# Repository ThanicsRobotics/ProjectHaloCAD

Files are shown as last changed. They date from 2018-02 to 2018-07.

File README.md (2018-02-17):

# ProjectHaloCAD
This is the official repository of the Thanics Halo open-source project. This is a project powered by the Raspberry Pi Compute Module 3, both the drone and controller use this module, along with several coprocessors. This project is not complete yet and all documaentation has not been uploaded, but feel free to follow along with our progress or use any of our 3D parts or software, as long as you attribute us.
## Background
### The Drone
The Thanics Halo drone utilizes stereo camera vision and ultrasonic sensors to accomplish spherical obstacle avoidance. The Halo drone is built to be versatile with a variety of cameras of different imaging types. The project focuses primarily on 360 (spherical) imaging and spherical video live streaming.
halo_assy_2017-jul-01_08-42-29pm-000_customizedview22054851270
### The Controller
The controller for the Halo drone is equally as innovative as the drone. This is a hybrid controller, able to be used either with two thumbs (traditional), or wrist-mounted for voice or touchscreen control.
halo controller v137 2
## Files
### MCAD Files: 
All mechanical part files for the project (source files are in Fusion 360 archive file .f3d or .f3z)
### ECAD Files: 
All electronics schematics, libraries and Autodesk EAGLE source .sch and .brd files
### Block Diagrams
Higher-level system block diagrams for the Drone and Controller
### Software:
For this project's source code, see our other repository: https://github.com/ThanicsRobotics/ProjectHalo

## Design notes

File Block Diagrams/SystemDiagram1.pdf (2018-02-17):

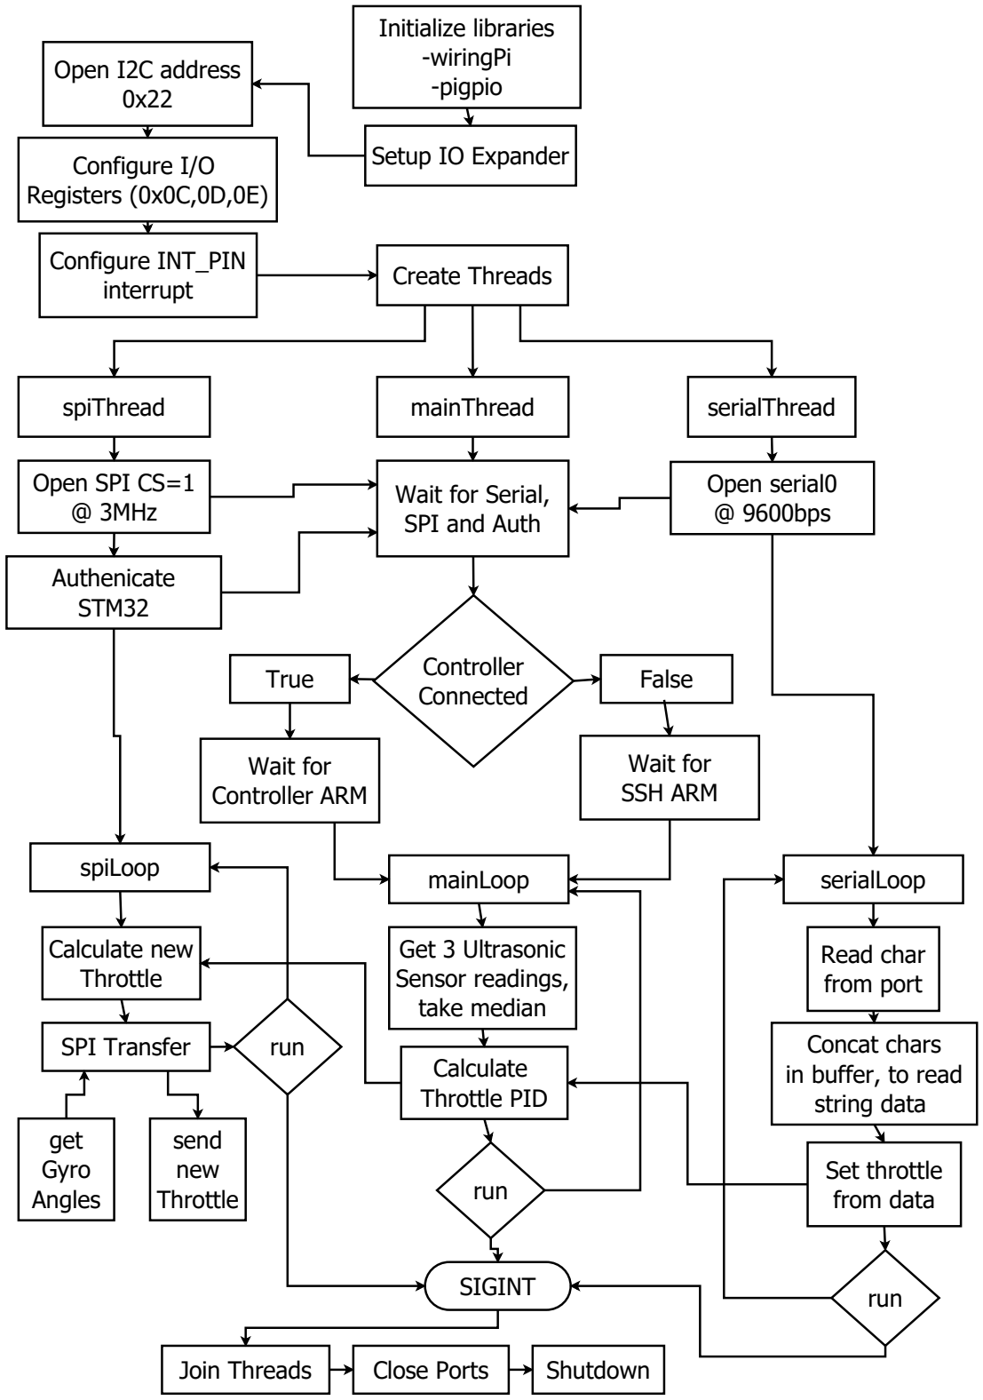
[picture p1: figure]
Initialize libraries -wiringPi -pigpio; Controller; Connected True; False; Wait for Controller ARM; Setup IO Expander; Open I2C address 0x22; Configure I/O Registers (0x0C,0D,0E); Configure INT_PIN; interrupt; Create Threads; spiThread; mainThread; serialThread; Open SPI CS=1 @ 3MHz; Authenicate STM32; Wait for Serial, SPI and Auth; Open serial0 @ 9600bps; Wait for SSH ARM; mainLoop; Get 3 Ultrasonic Sensor readings, take median; Calculate Throttle PID; spiLoop; serialLoop; run; Calculate new Throttle; SPI Transfer; get Gyro Angles; send new Throttle; Read char from port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

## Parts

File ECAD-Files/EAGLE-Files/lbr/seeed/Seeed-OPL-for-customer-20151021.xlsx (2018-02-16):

OPL list
Seeed SKU | MPN | Description | Category | Package | Manufacturer | Datasheet | Price（$）/pcs | Pieces/set | Solder points Qty | Assem.Cost/pcs（$） | Image URL | Distributor-URL
306010055 | FC-135 | SMD Crystal ABS07-32.768KHZ-7pF-20ppm-70K; | Crystal Oscillator | 2P-L3.2*W1.5mm | Xinhunjing | http://www.seeedstudio.com/wiki/images/7/78/306010055.pdf | 0.350 | 5 | 4 | 0.40 |  | http://www.seeedstudio.com/depot/OPLopen-parts-library-catalog-c-136_138/#306010055
306010005 | 49S | DIP Crystal 25MHz-20pF-20ppm;HC49US | Crystal Oscillator | HC49US | Xinhunjing | http://www.seeedstudio.com/wiki/images/5/5e/306010005.pdf | 0.150 | 10 | 2 | 0.20 |  | http://www.seeedstudio.com/depot/OPLopen-parts-library-catalog-c-136_138/#306010005
306010037 | 49S/18PF | DIP Crystal 16MHz-18pF-30ppm-50R; | Crystal Oscillator | HC49/US | Xinhunjing | http://www.seeedstudio.com/wiki/images/5/57/306010037.pdf | 0.150 | 10 | 2 | 0.20 |  | http://www.seeedstudio.com/depot/OPLopen-parts-library-catalog-c-136_138/#306010037
306010054 | X053201602002 | SMD 16MHz-8pF-20ppm-40R | Crystal Oscillator | 2P-SMD-5.0X3.2 | JINGPENGYUAN | http://www.seeedstudio.com/wiki/images/9/9f/0500290P1.pdf | 0.350 | 5 | 2 | 0.20 |  | http://www.seeedstudio.com/depot/OPLopen-parts-library-catalog-c-136_138/#0500290P1
306010047 | 5032/2P | SMD Crystal 12Mhz-20pF-20ppm-40R; | Crystal Oscillator | 2P-L5.0*W3.2mm | Xinhunjing | http://www.seeedstudio.com/wiki/images/c/c7/306010047.pdf | 0.450 | 5 | 2 | 0.20 |  | http://www.seeedstudio.com/depot/OPLopen-parts-library-catalog-c-136_138/#306010047
306010004 | 5032/4P | SMD Crystal 8MHz-20pF-20ppm; | Crystal Oscillator | 2P-L5.0*W3.2mm | Xinhunjing | http://www.seeedstudio.com/wiki/images/9/91/306010004.pdf | 0.450 | 5 | 2 | 0.20 |  | http://www.seeedstudio.com/depot/OPLopen-parts-library-catalog-c-136_138/#306010004
306010033 | 49S8M | DIP Crystal 8MHz-20pF-20ppm-60R; | Crystal Oscillator | HC49S | Xinhunjing | http://www.seeedstudio.com/wiki/images/c/ca/306010033.pdf | 0.150 | 10 | 2 | 0.20 |  | http://www.seeedstudio.com/depot/OPLopen-parts-library-catalog-c-136_138/#306010033
305030028 | 2N7002,215 | SMD MOSFET N-CH 60V-300mA Logic Level FET; | Transistor | SOT-23 | NXP | http://www.seeedstudio.com/wiki/images/c/c6/305030028.pdf | 0.050 | 30 | 3 | 0.30 |  | http://www.seeedstudio.com/depot/OPLopen-parts-library-catalog-c-136_138/#305030028
305030015 | CJ2302 | SMD MOSFET N-CH 20V 2.1A | Transistor | SOT23 | JCET | http://www.seeedstudio.com/wiki/images/e/e7/0440200P1.pdf | 0.100 | 10 | 3 | 0.30 |  | http://www.seeedstudio.com/depot/OPLopen-parts-library-catalog-c-136_138/#0440200P1
305030018 | Si2343CDS | SMD MOSFET P-CH 30V-5.9A | Transistor | SOT-23 | Vishay Siliconix |  | 0.700 | 5 | 3 | 0.30 |  | http://www.seeedstudio.com/depot/OPLopen-parts-library-catalog-c-136_138/#305030018
305030014 | CJ2305 | SMD MOSFET P-CH -8V -4.1A | Transistor | SOT-23 | JCET | http://www.seeedstudio.com/wiki/images/a/ac/0440210P1.pdf | 0.100 | 10 | 3 | 0.30 |  | http://www.seeedstudio.com/depot/OPLopen-parts-library-catalog-c-136_138/#0440210P1
305010018 | S9013 | SMD Transistors NPN 25V-500mA | Transistor | SOT-23 | JCET | http://www.seeedstudio.com/wiki/images/6/67/0400000P1.pdf | 0.040 | 50 | 3 | 0.30 |  | http://www.seeedstudio.com/depot/OPLopen-parts-library-catalog-c-136_138/#0400000P1
305020006 | S8550 | SMD Transistors PNP 25V-500mA | Transistor | SOT-23 |  | http://www.seeedstudio.com/wiki/images/e/e5/0410030P1.pdf | 0.040 | 50 | 3 | 0.30 |  | http://www.seeedstudio.com/depot/OPLopen-parts-library-catalog-c-136_138/#0410030P1
305010017 | S8050 | SMD Transistors NPN 25V-500mW; | Transistor | SOT-23 | JCET | http://www.seeedstudio.com/wiki/images/b/ba/305010017.pdf | 0.040 | 50 | 3 | 0.30 |  | http://www.seeedstudio.com/depot/OPLopen-parts-library-catalog-c-136_138/#305010017
305010022 | S9014J6 | SMD Transistor NPN 50V-100mA; | Transistor | SOT-23 | Changjiang | http://www.seeedstudio.com/wiki/images/2/2c/305010022.pdf | 0.050 | 30 | 3 | 0.30 |  | http://www.seeedstudio.com/depot/OPLopen-parts-library-catalog-c-136_138/#305010022
312010004 | KS-12065D03YA | DIP Buzzer 3V,30mA, 2700±300Hz | Audio product | 2P-7.6-D12*H6.5mm | Guangjixing | http://www.seeedstudio.com/wiki/images/c/cb/312020003.pdf | 0.500 | 5 | 2 | 0.20 |  | http://www.seeedstudio.com/depot/OPLopen-parts-library-catalog-c-136_138/#312010004
302020027 | TAJD477M006RNJ | SMD CAP Tantalum 470uF-6.3V;D | Capacitor | AVX-D | AVX |  | 0.500 | 5 | 2 | 0.20 |  | http://www.seeedstudio.com/depot/OPLopen-parts-library-catalog-c-136_138/#302020027
302030031 |  | DIP CAP Aluminum 100uF-16V | Capacitor | Radial-D5.0*H7.0mm | JWCO | http://www.seeedstudio.com/wiki/images/1/14/302030031.pdf | 0.030 | 50 | 2 | 0.20 |  | http://www.seeedstudio.com/depot/OPLopen-parts-library-catalog-c-136_138/#302030031
302020025 | TAJC107K010RNJ | SMD CAP Tantalum 100uF-10V 10% | Capacitor | AVX-C | AVX | http://www.seeedstudio.com/wiki/images/a/ae/0130170P1.pdf | 0.200 | 10 | 2 | 0.20 |  | http://www.seeedstudio.com/depot/OPLopen-parts-library-catalog-c-136_138/#0130170P1
302020022 | TAJC476K016RNJ | SMD CAP Tantalum 47uF-16V | Capacitor | AVX-C | AVX | http://www.seeedstudio.com/wiki/images/c/c7/302020022.pdf | 0.200 | 10 | 2 | 0.20 |  | http://www.seeedstudio.com/depot/OPLopen-parts-library-catalog-c-136_138/#302020022
302020020 | TAJB476K010RNJ | SMD CAP Tantalum 47uF-10V 10% | Capacitor | AVX-B | AVX | http://www.seeedstudio.com/wiki/images/f/fb/0130180P1.pdf | 0.200 | 10 | 2 | 0.20 |  | http://www.seeedstudio.com/depot/OPLopen-parts-library-catalog-c-136_138/#0130180P1
302020005 | TAJC476K006RNJ | SMD CAP Tantalum 47uF-6.3V | Capacitor | AVX-A | AVX |  | 0.150 | 20 | 2 | 0.20 |  | http://www.seeedstudio.com/depot/OPLopen-parts-library-catalog-c-136_138/#302020005
302020026 | TAJC226K025RNJ | SMD CAP Tantalum 22uF-25V 10% 2312 | Capacitor | AVX-C | AVX | http://www.seeedstudio.com/wiki/images/f/fd/0130360P1.pdf | 0.370 | 10 | 2 | 0.20 |  | http://www.seeedstudio.com/depot/OPLopen-parts-library-catalog-c-136_138/#0130360P1
302020021 | TAJB226K010RNJ | SMD CAP Tantalum 22uF-10V 10% | Capacitor | AVX-B | AVX | http://www.seeedstudio.com/wiki/images/8/82/0130240P1.pdf | 0.130 | 20 | 2 | 0.20 |  | http://www.seeedstudio.com/depot/OPLopen-parts-library-catalog-c-136_138/#0130240P1
302010171 | CC0805MKX5R5BB226 | SMD CAP Ceramic 22uF-6.3V-20%-X5R; | Capacitor | 0805 | YAGEO |  | 0.050 | 50 | 2 | 0.20 |  | http://www.seeedstudio.com/depot/OPLopen-parts-library-catalog-c-136_138/#302010171
302010181 | CC1206KKX5R8BB106 | SMD CAP Ceramic 10uF-25V-10%-X5R | Capacitor | 1206 | YAGEO |  | 0.130 | 20 | 2 | 0.20 |  | http://www.seeedstudio.com/depot/OPLopen-parts-library-catalog-c-136_138/#302010181
302010178 | CC0805KKX5R8BB106 | SMD CAP Ceramic 10uF-25V-10%-X5R | Capacitor | 0805 | YAGEO | http://www.seeedstudio.com/wiki/images/2/20/0100080P1.pdf | 0.050 | 50 | 2 | 0.20 |  | http://www.seeedstudio.com/depot/OPLopen-parts-library-catalog-c-136_138/#0100080P1
302020019 | TAJB106K016RNJ | SMD CAP Tantalum 10uF-16V 10% | Capacitor | AVX-B | AVX | http://www.seeedstudio.com/wiki/images/f/f6/0130120P1.pdf | 0.150 | 20 | 2 | 0.20 |  | http://www.seeedstudio.com/depot/OPLopen-parts-library-catalog-c-136_138/#0130120P1
302020002 | TAJA106K016RNJ | SMD CAP Tantalum 10uF-16V 10% | Capacitor | AVX-A | AVX | http://www.seeedstudio.com/wiki/images/1/1b/0130050P1.pdf | 0.130 | 20 | 2 | 0.20 |  | http://www.seeedstudio.com/depot/OPLopen-parts-library-catalog-c-136_138/#0130050P1
302020011 | TAJA106K010RNJ | SMD CAP Tantalum 10uF-10V 10% | Capacitor | AVX-A | AVX | http://www.seeedstudio.com/wiki/images/5/59/0130040P1.pdf (http://www.seeedstudio.com/wiki/images/0/0d/302010146.pdf) | 0.130 | 20 | 2 | 0.20 |  | http://www.seeedstudio.com/depot/OPLopen-parts-library-catalog-c-136_138/#0130040P1
302010243 | CC1206KKX5R9BB475 | SMD CAP Ceramic 4.7uF-50V-10%-X5R; | Capacitor | 1206 | YAGEO |  | 0.250 | 10 | 2 | 0.20 |  | http://www.seeedstudio.com/depot/OPLopen-parts-library-catalog-c-136_138/#302010243
302010146 | CC0805KKX5R8BB475 | SMD CAP Ceramic 4.7uF-25V-10%-X5R;0805 | Capacitor | C0805 | YAGEO | http://www.seeedstudio.com/wiki/images/0/0d/302010146.pdf | 0.040 | 50 | 2 | 0.20 |  | http://www.seeedstudio.com/depot/OPLopen-parts-library-catalog-c-136_138/#302010146
302010111 | CC0603KRX5R6BB475 | SMD CAP Ceramic 4.7uF-10V-10%-X5R; | Capacitor | 0603 | YAGEO |  | 0.040 | 50 | 2 | 0.20 |  | http://www.seeedstudio.com/depot/OPLopen-parts-library-catalog-c-136_138/#302010111
302010019 | CC0402MRX5R5BB475 | SMD CAP Ceramic 4.7uF-6.3V-20%-X5R | Capacitor | 0402 | YAGEO |  | 0.200 | 10 | 2 | 0.20 |  | http://www.seeedstudio.com/depot/OPLopen-parts-library-catalog-c-136_138/#302010019
302010148 | CC0805KKX7R8BB225 | SMD CAP Ceramic 2.2uF-25V-10%-X7R;0805 | Capacitor | C0805 | YAGEO | http://www.seeedstudio.com/wiki/images/a/ac/302010056.pdf | 0.050 | 50 | 2 | 0.20 |  | http://www.seeedstudio.com/depot/OPLopen-parts-library-catalog-c-136_138/#302010148
302010179 | CC0805KKX7R8BB105 | SMD CAP Ceramic 1uF-25V-10%-X7R | Capacitor | 0805 | YAGEO | http://www.seeedstudio.com/wiki/images/8/89/0100440P1.pdf (http://www.seeedstudio.com/wiki/images/a/ac/302010056.pdf) | 0.030 | 50 | 2 | 0.20 |  | http://www.seeedstudio.com/depot/OPLopen-parts-library-catalog-c-136_138/#0100440P1
302010139 | CC0603KRX7R8BB105 | SMD CAP Ceramic 1uF-25V-10%-X7R | Capacitor | 0603 | YAGEO | http://www.seeedstudio.com/wiki/images/a/af/0100340P1.pdf (http://www.seeedstudio.com/wiki/File:302010056.pdf) | 0.015 | 100 | 2 | 0.20 |  | http://www.seeedstudio.com/depot/OPLopen-parts-library-catalog-c-136_138/#0100340P1
302010040 | CC0402KRX5R6BB105 | SMD CAP Ceramic 1uF-10V-10%-X5R | Capacitor | 0402 | YAGEO |  | 0.015 | 100 | 2 | 0.20 |  | http://www.seeedstudio.com/depot/OPLopen-parts-library-catalog-c-136_138/#302010040
302010073 | CC0603KRX7R8BB224 | SMD CAP Ceramic 220nF-25V-10%-X7R;0603 | Capacitor | 0603 | YAGEO | http://www.seeedstudio.com/wiki/images/a/ac/302010056.pdf | 0.015 | 100 | 2 | 0.20 |  | http://www.seeedstudio.com/depot/OPLopen-parts-library-catalog-c-136_138/#302010073
302010165 | CC0805KRX7R9BB104 | SMD CAP Ceramic 100nF-50V-10%-X7R; | Capacitor | 0805 | YAGEO | http://www.seeedstudio.com/wiki/File:302010056.pdf (http://www.seeedstudio.com/wiki/images/a/ac/302010056.pdf) | 0.015 | 100 | 2 | 0.20 |  | http://www.seeedstudio.com/depot/OPLopen-parts-library-catalog-c-136_138/#302010165
302010138 | CC0603KRX7R9BB104 | SMD CAP Ceramic 100nF-50V-10%-X7R | Capacitor | 0603 | YAGEO | http://www.seeedstudio.com/wiki/images/3/35/0100020P1.pdf | 0.015 | 100 | 2 | 0.20 |  | http://www.seeedstudio.com/depot/OPLopen-parts-library-catalog-c-136_138/#0100020P1
302010024 | CC0402KRX7R8BB104 | SMD CAP Ceramic 100nF-25V-10%-X7R | Capacitor | 0402 | YAGEO | http://www.seeedstudio.com/wiki/images/a/ac/302010056.pdf | 0.015 | 100 | 2 | 0.20 |  | http://www.seeedstudio.com/depot/OPLopen-parts-library-catalog-c-136_138/#302010024
302010002 | CC0402KRX7R8BB473 | SMD CAP Ceramic 47nF-25V-10%-X7R; | Capacitor | 0402 | YAGEO |  | 0.010 | 100 | 2 | 0.20 |  | http://www.seeedstudio.com/depot/OPLopen-parts-library-catalog-c-136_138/#302010002
302010088 | CC0603KRX7R9BB333 | SMD CAP Ceramic 33nF-50V-10%-X7R;0603 | Capacitor | 0603 | YAGEO | http://www.seeedstudio.com/wiki/images/a/ac/302010056.pdf | 0.015 | 100 | 2 | 0.20 |  | http://www.seeedstudio.com/depot/OPLopen-parts-library-catalog-c-136_138/#302010088
302010095 | CC0603KRX7R9BB223 | SMD CAP Ceramic 22nF-50V-10%-X7R;0603 | Capacitor | C0603 | YAGEO | http://www.seeedstudio.com/wiki/images/a/ac/302010056.pdf | 0.010 | 100 | 2 | 0.20 |  | http://www.seeedstudio.com/depot/OPLopen-parts-library-catalog-c-136_138/#302010095
302010202 |  | DIP CAP Ceramic Disc 10nF-50V-Y5V | Capacitor | Radial-Disc-2.5-D4.0mm |  |  | 0.015 | 100 | 2 | 0.20 |  | http://www.seeedstudio.com/depot/OPLopen-parts-library-catalog-c-136_138/#302010202
302010140 | CC0603KRX7R9BB103 | SMD CAP Ceramic 10nF-50V-10%-X7R | Capacitor | 0603 | YAGEO | http://www.seeedstudio.com/wiki/images/e/eb/0100350P1.pdf (http://www.seeedstudio.com/wiki/images/f/f0/302010067.pdf%20302010094) | 0.010 | 100 | 2 | 0.20 |  | http://www.seeedstudio.com/depot/OPLopen-parts-library-catalog-c-136_138/#0100350P1
302010006 | CC0402KRX7R9BB103 | SMD CAP Ceramic 10nF-50V-10%-X7R | Capacitor | 0402 | YAGEO | http://www.seeedstudio.com/wiki/images/f/f0/302010067.pdf | 0.010 | 100 | 2 | 0.20 |  | http://www.seeedstudio.com/depot/OPLopen-parts-library-catalog-c-136_138/#302010006
302010144 | CC0603KRX7R9BB472 | SMD CAP Ceramic 4.7nF-50V-10%-X7R | Capacitor | 0603 | YAGEO | http://www.seeedstudio.com/wiki/images/f/fd/0130360P1.pdf | 0.010 | 100 | 2 | 0.20 |  | http://www.seeedstudio.com/depot/OPLopen-parts-library-catalog-c-136_138/#0100850P1
302010056 | CC0603KRX7R9BB222 | SMD CAP Ceramic 2.2nF-50V-10%-X7R | Capacitor | 0603 | YAGEO | http://www.seeedstudio.com/wiki/images/a/ac/302010056.pdf | 0.010 | 100 | 2 | 0.20 |  | http://www.seeedstudio.com/depot/OPLopen-parts-library-catalog-c-136_138/#302010056
302010141 | CC0603KRX7R9BB102 | SMD CAP Ceramic 1nF-50V-10%-X7R | Capacitor | 0603 | YAGEO | http://www.seeedstudio.com/wiki/images/c/cf/0100370P1.pdf | 0.010 | 100 | 2 | 0.20 |  | http://www.seeedstudio.com/depot/OPLopen-parts-library-catalog-c-136_138/#0100370P1
302010005 | CC0402KRX7R9BB102 | SMD CAP Ceramic 1nF-50V-10%-X7R; | Capacitor | 0402 | YAGEO |  | 0.050 | 50 | 2 | 0.20 |  | http://www.seeedstudio.com/depot/OPLopen-parts-library-catalog-c-136_138/#302010005
302010094 | CC0603JRNPO9BN221 | SMD CAP Ceramic 220pF-50V-5%-NPO; | Capacitor | C0603 | YAGEO | http://www.seeedstudio.com/wiki/images/f/f0/302010067.pdf 302010094 (http://www.seeedstudio.com/wiki/File:302010067.pdf) | 0.020 | 100 | 2 | 0.20 |  | http://www.seeedstudio.com/depot/OPLopen-parts-library-catalog-c-136_138/#302010094
302010013 | CC0402JRNPO9BN221 | SMD CAP Ceramic 220pF-50V-5%-NPO | Capacitor | 0402 | YAGEO | http://www.seeedstudio.com/wiki/images/f/f0/302010067.pdf | 0.030 | 50 | 2 | 0.20 |  | http://www.seeedstudio.com/depot/OPLopen-parts-library-catalog-c-136_138/#302010013
302010076 | CC0603JRNPO9BN101 | SMD CAP Ceramic 100pF-50V-5%-NPO;0603 | Capacitor | 0603 | YAGEO | http://www.seeedstudio.com/wiki/images/f/f0/302010067.pdf | 0.010 | 100 | 2 | 0.20 |  | http://www.seeedstudio.com/depot/OPLopen-parts-library-catalog-c-136_138/#302010076
302010126 | CC0603JRNPO9BN390 | SMD CAP Ceramic 39pF-50V-5%-NPO;0603 | Capacitor | C0603 | YAGEO | http://www.seeedstudio.com/wiki/images/f/f0/302010067.pdf (http://www.seeedstudio.com/wiki/images/0/03/0100230P1.pdf) | 0.010 | 100 | 2 | 0.20 |  | http://www.seeedstudio.com/depot/OPLopen-parts-library-catalog-c-136_138/#302010126
302010150 | CC0805JRNPO9BN270 | SMD CAP Ceramic 27pF-50V-5%-NPO | Capacitor | 0805 | YAGEO | http://www.seeedstudio.com/wiki/images/b/be/320020004.png | 0.030 | 50 | 2 | 0.20 |  | http://www.seeedstudio.com/depot/OPLopen-parts-library-catalog-c-136_138/#302010150
302010142 | CC0603JRNPO9BN270 | SMD CAP Ceramic 27pF-50V-5%-NPO | Capacitor | 0603 | YAGEO | http://www.seeedstudio.com/wiki/images/0/01/0100410P1.pdf (http://www.seeedstudio.com/wiki/images/b/be/320020004.png) | 0.010 | 100 | 2 | 0.20 |  | http://www.seeedstudio.com/depot/OPLopen-parts-library-catalog-c-136_138/#0100410P1
302010027 | CC0402JRNPO9BN270 | SMD CAP Ceramic 27pF-50V-5%-NPO | Capacitor | 0402 | YAGEO | http://www.seeedstudio.com/wiki/images/b/be/320020004.png | 0.010 | 100 | 2 | 0.20 |  | http://www.seeedstudio.com/depot/OPLopen-parts-library-catalog-c-136_138/#302010027
302010143 | CC0603JRNPO9BN220 | SMD CAP Ceramic 22pF-50V-5%-NPO | Capacitor | 0603 | YAGEO | http://www.seeedstudio.com/wiki/images/7/73/0100620P1.pdf | 0.010 | 100 | 2 | 0.20 |  | http://www.seeedstudio.com/depot/OPLopen-parts-library-catalog-c-136_138/#0100620P1
302010018 | CC0402JRNPO9BN220 | SMD CAP Ceramic 22pF-50V-5%-NPO | Capacitor | 0402 | YAGEO | http://www.seeedstudio.com/wiki/File:302010067.pdf (http://www.seeedstudio.com/wiki/images/b/be/320020004.png) | 0.010 | 100 | 2 | 0.20 |  | http://www.seeedstudio.com/depot/OPLopen-parts-library-catalog-c-136_138/#302010018
302010162 | CC0805JRNPO9BN180 | SMD CAP Ceramic 18pF-50V-5%-NPO | Capacitor | 0805 | YAGEO |  | 0.010 | 100 | 2 | 0.20 |  | http://www.seeedstudio.com/depot/OPLopen-parts-library-catalog-c-136_138/#302010162
302010016 | CC0402JRNPO9BN180 | SMD CAP Ceramic 18pF-50V-5%-NPO | Capacitor | 0402 | YAGEO |  | 0.010 | 100 | 2 | 0.20 |  | http://www.seeedstudio.com/depot/OPLopen-parts-library-catalog-c-136_138/#302010016
302010083 | CC0603JRNPO9BN180 | SMD CAP Ceramic 18pF-50V-5%-NPO; | Capacitor | 0603 | YAGEO | http://www.seeedstudio.com/wiki/images/7/77/320020027.png | 0.010 | 100 | 2 | 0.20 |  | http://www.seeedstudio.com/depot/OPLopen-parts-library-catalog-c-136_138/#302010083
302010082 | CC0603JRNPO9BN150 | SMD CAP Ceramic 15pF-50V-5%-NPO;0603 | Capacitor | 0603 | YAGEO | http://www.seeedstudio.com/wiki/images/f/f0/302010067.pdf (http://www.seeedstudio.com/wiki/images/e/ef/320020003.png) | 0.010 | 100 | 2 | 0.20 |  | http://www.seeedstudio.com/depot/OPLopen-parts-library-catalog-c-136_138/#302010082
302010067 | CC0603JRNPO9BN120 | SMD CAP Ceramic 12pF-50V-5%-NP0 | Capacitor | 0603 | YAGEO | http://www.seeedstudio.com/wiki/images/f/f0/302010067.pdf | 0.010 | 100 | 2 | 0.20 |  | http://www.seeedstudio.com/depot/OPLopen-parts-library-catalog-c-136_138/#302010067
302010097 | CC0603JRNPO9BN100 | SMD CAP Ceramic 10pF-50V-5%-NPO | Capacitor | 0603 | YAGEO | http://www.seeedstudio.com/wiki/images/b/be/320020004.png | 0.010 | 100 | 2 | 0.20 |  | http://www.seeedstudio.com/depot/OPLopen-parts-library-catalog-c-136_138/#302010097
302010001 | CC0402JRNPO9BN100 | SMD CAP Ceramic 10pF-50V-5%-NPO | Capacitor | 0402 | YAGEO |  | 0.010 | 100 | 2 | 0.20 |  | http://www.seeedstudio.com/depot/OPLopen-parts-library-catalog-c-136_138/#302010001
302010223 | CC0402CRNPO9BN2R2 | SMD CAP Ceramic 2.2pF-50V-0.25PF-NPO | Capacitor | 0402 | YAGEO | http://www.seeedstudio.com/wiki/images/b/be/320020004.png | 0.010 | 100 | 2 | 0.20 |  | http://www.seeedstudio.com/depot/OPLopen-parts-library-catalog-c-136_138/#302010223
302010102 | CC0603CRNPO9BN2R2 | SMD CAP Ceramic 2.2pF-50V-0.25pF-NPO | Capacitor | 0603 | YAGEO |  | 0.010 | 100 | 2 | 0.20 |  | http://www.seeedstudio.com/depot/OPLopen-parts-library-catalog-c-136_138/#302010102
302010046 | GRM1555C1H1R8BA01D | SMD CAP Ceramic 1.8pF-50V-0.1pF-NPO | Capacitor | 0402 | Murata |  | 0.010 | 100 | 2 | 0.20 |  | http://www.seeedstudio.com/depot/OPLopen-parts-library-catalog-c-136_138/#302010046
320020037 | P125-1102A0BS116A3 | DIP White Male Header VERT; | Connector | 1*2P-2.54-2.54-11.6/3.0mm | YXCON | http://www.seeedstudio.com/wiki/images/b/be/320020004.png (http://www.seeedstudio.com/wiki/images/c/cb/320020019.png) | 0.100 | 20 | 2 | 0.20 |  | http://www.seeedstudio.com/depot/OPLopen-parts-library-catalog-c-136_138/#320020037
320020015 | P125-1102A0BS116A2 | DIP Blue Male Header VERT | Connector | 1*2P-2.54-2.54-11.6/3.0mm | YXCON | http://www.seeedstudio.com/wiki/images/b/be/320020004.png | 0.100 | 20 | 2 | 0.20 |  | http://www.seeedstudio.com/depot/OPLopen-parts-library-catalog-c-136_138/#320020015
320020016 | P125-1102A0BS116A1 | DIP Black Male Header VERT | Connector | 1*2P-2.54-2.54-11.6/3.0mm | YXCON | http://www.seeedstudio.com/wiki/images/b/be/320020004.png | 0.100 | 20 | 2 | 0.20 |  | http://www.seeedstudio.com/depot/OPLopen-parts-library-catalog-c-136_138/#320020016
320020079 |  | DIP-Black-Male-Header-VERT-3P | Connector | 1X3P-2.54-2.54-11.6/3.0 | YXCON | http://www.seeedstudio.com/wiki/images/0/02/3460810P1.pdf (http://www.seeedstudio.com/wiki/images/b/be/320020004.png) | 0.100 | 20 | 3 | 0.30 |  | http://www.seeedstudio.com/depot/OPLopen-parts-library-catalog-c-136_138/#3460810P1
320020038 | P125-1103A0BS116A1 | DIP White Male Header VERT; | Connector | 1*3P-2.54-2.54-11.6/3.0mm | YXCON | http://www.seeedstudio.com/wiki/images/b/be/320020004.png | 0.120 | 20 | 3 | 0.30 |  | http://www.seeedstudio.com/depot/OPLopen-parts-library-catalog-c-136_138/#320020038
320020061 | P125-1103A0BR138A1 | DIP Black Male Header R/A; | Connector | 1*3P-2.54-2.54-6.0mm-90D-1 | YXCON |  | 0.120 | 20 | 3 | 0.30 |  | http://www.seeedstudio.com/depot/OPLopen-parts-library-catalog-c-136_138/#320020061
320020077 | P125-12A1BS116A1 | DIP Black Male Header | Connector | 2X3P-2.54-2.54-11.6/3.0 | YXCON | http://www.seeedstudio.com/wiki/images/7/72/3460180P1.pdf (http://www.seeedstudio.com/wiki/images/8/8b/320020018.png) | 0.060 | 20 | 6 | 0.60 |  | http://www.seeedstudio.com/depot/OPLopen-parts-library-catalog-c-136_138/#3460180P1
320020027 | P125-1203A0BS116A2 | DIP Yellow Male Header VERT; | Connector | 2*3P-2.54-2.54-11.6/3.0mm | YXCON | http://www.seeedstudio.com/wiki/images/7/77/320020027.png | 0.100 | 20 | 6 | 0.60 |  | http://www.seeedstudio.com/depot/OPLopen-parts-library-catalog-c-136_138/#320020027
320020003 | P125-1203A0BS116A1 | DIP Blue Male Header VERT; | Connector | 2*3P-2.54-2.54-11.6/3.0mm | YXCON | http://www.seeedstudio.com/wiki/images/e/ef/320020003.png (http://www.seeedstudio.com/wiki/images/2/25/320020010.pdf) | 0.150 | 20 | 6 | 0.60 |  | http://www.seeedstudio.com/depot/OPLopen-parts-library-catalog-c-136_138/#320020003
320020017 | P125-1104A0BS116A1 | DIP Black Male Header VERT | Connector | 1*4P-2.54-2.54-11.6/3.0mm | YXCON | http://www.seeedstudio.com/wiki/images/f/fb/320020089.png | 0.100 | 20 | 4 | 0.40 |  | http://www.seeedstudio.com/depot/OPLopen-parts-library-catalog-c-136_138/#320020017
320020005 | P125-1106A0BS116A1 | DIP Blue Male Header VERT | Connector | 1*6P-2.54-2.54-11.6/3.0mm | YXCON | http://www.seeedstudio.com/wiki/images/b/be/320020004.png | 0.100 | 20 | 6 | 0.60 |  | http://www.seeedstudio.com/depot/OPLopen-parts-library-catalog-c-136_138/#320020005
320020078 | P125-1106A1BS116A1 | DIP Black Male Header | Connector | 1X6P-2.54-2.54-11.6/3.0mm | YXCON | http://www.seeedstudio.com/wiki/images/2/2d/3460650P1.pdf | 0.100 | 20 | 6 | 0.60 |  | http://www.seeedstudio.com/depot/OPLopen-parts-library-catalog-c-136_138/#3460650P1
320020022 | P125-1106A0BS116A2 | DIP White Male Header VERT; | Connector | 1*6P-2.54-2.54-11.6/3.0mm | YXCON | http://www.seeedstudio.com/wiki/images/b/be/320020004.png (http://www.seeedstudio.com/wiki/images/0/0d/320030039.pdf) | 0.100 | 20 | 6 | 0.60 |  | http://www.seeedstudio.com/depot/OPLopen-parts-library-catalog-c-136_138/#320020022
320020024 | P125-1106B0BA2 | SMD Blue Male Header R/A; | Connector | 1*6P-2.54-2.54-9.3/6.0mm-2 | YXCON | http://www.seeedstudio.com/wiki/images/e/ef/320120007.pdf | 0.100 | 20 | 6 | 0.60 |  | http://www.seeedstudio.com/depot/OPLopen-parts-library-catalog-c-136_138/#320020024
320020031 | P125-1106B0BA1 | SMD Black Male Header R/A; | Connector | 1*6P-2.54-2.54-9.3/6.0mm-2 | YXCON | http://www.seeedstudio.com/wiki/images/d/d3/320030100.png | 0.100 | 20 | 6 | 0.60 |  | http://www.seeedstudio.com/depot/OPLopen-parts-library-catalog-c-136_138/#320020031
320020019 | P125-1106A0BR138A1 | DIP Black Short Male Header R/A; | Connector | 1X6P-2.54-2.54-6.0mm-90D-1 | YXCON | http://www.seeedstudio.com/wiki/images/c/cb/320020019.png (http://www.seeedstudio.com/wiki/images/a/a7/320030035.png) | 0.100 | 20 | 6 | 0.60 |  | http://www.seeedstudio.com/depot/OPLopen-parts-library-catalog-c-136_138/#320020019
320020070 | P125-1106A0BR138A2 | DIP Black Male Header R/A; | Connector | 1*6P-2.54-2.54-6.0mm-90D-2 | YXCON | http://www.seeedstudio.com/wiki/images/1/11/320030011.png | 0.100 | 20 | 6 | 0.60 |  | http://www.seeedstudio.com/depot/OPLopen-parts-library-catalog-c-136_138/#320020070
320020004 | P125-1108A0BS116A1 | DIP Blue Male Header VERT | Connector | 1*8P-2.54-2.54-11.6/3.0mm | YXCON | http://www.seeedstudio.com/wiki/images/b/be/320020004.png (http://www.seeedstudio.com/wiki/images/0/0d/320030039.pdf) | 0.100 | 20 | 8 | 0.80 |  | http://www.seeedstudio.com/depot/OPLopen-parts-library-catalog-c-136_138/#320020004
320020021 | P125-1108A0BS116A2 | DIP White Male Header VERT; | Connector | 1*8P-2.54-2.54-11.6/3.0mm | YXCON | http://www.seeedstudio.com/wiki/images/b/be/320020004.png | 0.100 | 20 | 8 | 0.80 |  | http://www.seeedstudio.com/depot/OPLopen-parts-library-catalog-c-136_138/#320020021
320020080 | P125-1108A1BS116A1 | DIP-Black-Male-Header-VERT-8P | Connector | 1X8P-2.54-2.54-11.6/3.0 | YXCON | http://www.seeedstudio.com/wiki/images/b/b5/3461050P1.pdf (http://www.seeedstudio.com/wiki/images/0/0d/320030039.pdf) | 0.100 | 20 | 8 | 0.80 |  | http://www.seeedstudio.com/depot/OPLopen-parts-library-catalog-c-136_138/#3461050P1
320020023 | P125-1108B0BA2 | SMD Blue Male Header R/A; | Connector | 1*8P-2.54-2.54-9.3/6.0mm-2 | YXCON | http://www.seeedstudio.com/wiki/images/0/0d/320030039.pdf | 0.120 | 20 | 8 | 0.80 |  | http://www.seeedstudio.com/depot/OPLopen-parts-library-catalog-c-136_138/#320020023
320020018 | P220-1110A0BS087A1 | DIP White Male Header VERT; | Connector | 1*10P-2.0-2.0-8.7/2.8mm | YXCON | http://www.seeedstudio.com/wiki/images/8/8b/320020018.png (http://www.seeedstudio.com/wiki/images/0/0d/320030039.pdf) | 0.200 | 10 | 10 | 1.00 |  | http://www.seeedstudio.com/depot/OPLopen-parts-library-catalog-c-136_138/#320020018
320020074 | P125-1110A0BR138A1 | DIP Black Male Header R/A; | Connector | 1*10P-2.54-2.54-6.0mm-90D-1 | YXCON | http://www.seeedstudio.com/wiki/images/e/e3/3460540P1.pdf | 0.120 | 20 | 10 | 1.00 |  | http://www.seeedstudio.com/depot/OPLopen-parts-library-catalog-c-136_138/#320020074
320020010 |  | DIP Black Male Header VERT; | Connector | 1*40P-2.54-2.54-11.6/3.0mm | YXCON | http://www.seeedstudio.com/wiki/images/2/25/320020010.pdf | 0.200 | 5 | 40 | 4.00 |  | http://www.seeedstudio.com/depot/OPLopen-parts-library-catalog-c-136_138/#320020010
320020089 | P220-1140A0BS087A1 | DIP White Male Header VERT; | Connector | 1*40P-2.0-2.0-8.7-2.8mm | YXCON | http://www.seeedstudio.com/wiki/images/f/fb/320020089.png | 0.250 | 5 | 40 | 4.00 |  | http://www.seeedstudio.com/depot/OPLopen-parts-library-catalog-c-136_138/#320020089
320020032 | P125-1140B0BA1 | SMD Black Male Header R/A; | Connector | 1*40P-2.0-2.0-4.0mm-2 | YXCON | http://www.seeedstudio.com/wiki/images/8/87/320030014.png | 0.400 | 5 | 40 | 4.00 |  | http://www.seeedstudio.com/depot/OPLopen-parts-library-catalog-c-136_138/#320020032
320020013 | P125-1140A0BR138A2 | DIP Black Short Male Header R/A; | Connector | 1*40P-2.54-2.54-6.0mm-90D-1 | YXCON |  | 0.400 | 5 | 40 | 4.00 |  | http://www.seeedstudio.com/depot/OPLopen-parts-library-catalog-c-136_138/#320020013
320030023 | F185-1102A1BSYA1 | DIP Black Female Header VERT; | Connector | 1*2P-2.54-8.5mm | YXCON | http://www.seeedstudio.com/wiki/images/0/0d/320030039.pdf | 0.150 | 10 | 2 | 0.20 |  | http://www.seeedstudio.com/depot/OPLopen-parts-library-catalog-c-136_138/#320030023
320120007 | GSL009-5.0-02P-12 | DIP Female Blue; | Connector | 2P-5.0 | SENGER | http://www.seeedstudio.com/wiki/images/e/ef/320120007.pdf (http://www.seeedstudio.com/wiki/images/0/0d/320030039.pdf) | 0.500 | 10 | 2 | 0.20 |  | http://www.seeedstudio.com/depot/OPLopen-parts-library-catalog-c-136_138/#320120007
320030100 | F185-1103A1BRYA1 | DIP Black Female Header; | Connector | 1*3P-2.54-8.5-90D | YXCON | http://www.seeedstudio.com/wiki/images/d/d3/320030100.png | 0.100 | 20 | 3 | 0.30 |  | http://www.seeedstudio.com/depot/OPLopen-parts-library-catalog-c-136_138/#320030100
320030035 | F185-1203A1BMYA1 | SMD Blue Female Header VERT | Connector | 2*3P-2.54-8.5mm | YXCON | http://www.seeedstudio.com/wiki/images/a/a7/320030035.png | 0.270 | 10 | 6 | 0.60 |  | http://www.seeedstudio.com/depot/OPLopen-parts-library-catalog-c-136_138/#320030035
320030011 | F185-1203A1BSYA1 | DIP Black Female Header VERT | Connector | 2*3P-2.54-8.5mm | YXCON | http://www.seeedstudio.com/wiki/images/1/11/320030011.png (http://www.seeedstudio.com/wiki/images/2/2d/320030013.png) | 0.200 | 10 | 6 | 0.60 |  | http://www.seeedstudio.com/depot/OPLopen-parts-library-catalog-c-136_138/#320030011
320030017 | F185-1104A1BSYA1 | DIP Black Female Header VERT | Connector | 1*4P-2.54-8.5mm | YXCON | http://www.seeedstudio.com/wiki/images/0/0d/320030039.pdf (http://www.seeedstudio.com/wiki/images/c/c9/320030076.png) | 0.150 | 10 | 4 | 0.40 |  | http://www.seeedstudio.com/depot/OPLopen-parts-library-catalog-c-136_138/#320030017
320030066 |  | DIP Long Blue Female Header | Connector | 2X3P-2.54-8.5+1.5-12.3 | YXCON | http://www.seeedstudio.com/wiki/images/0/01/3461240P1.pdf (http://www.seeedstudio.com/wiki/images/7/70/320030001.pdf) | 0.250 | 10 | 6 | 0.60 |  | http://www.seeedstudio.com/depot/OPLopen-parts-library-catalog-c-136_138/#3461240P1
320030019 | F185-1106A1BSYA3 | DIP Yellow Female Header VERT; | Connector | 1*6P-2.54-8.5mm | YXCON | http://www.seeedstudio.com/wiki/images/0/0d/320030039.pdf | 0.200 | 10 | 6 | 0.60 |  | http://www.seeedstudio.com/depot/OPLopen-parts-library-catalog-c-136_138/#320030019
320030012 | F185-1106A1BSYA2 | DIP Long Black Female Header VERT | Connector | 1*6P-2.54-8.5mm | YXCON | http://www.seeedstudio.com/wiki/images/0/0d/320030039.pdf (http://www.seeedstudio.com/wiki/images/f/f2/3460170P1.pdf) | 0.250 | 10 | 6 | 0.60 |  | http://www.seeedstudio.com/depot/OPLopen-parts-library-catalog-c-136_138/#320030012
320030004 | F185-1106A1BSYA1 | DIP Blue Female Header VERT | Connector | 1*6P-2.54-8.5mm | YXCON | http://www.seeedstudio.com/wiki/images/0/0d/320030039.pdf (http://www.seeedstudio.com/wiki/images/c/c5/320030020.png) | 0.200 | 10 | 6 | 0.60 |  | http://www.seeedstudio.com/depot/OPLopen-parts-library-catalog-c-136_138/#320030004
320030063 | F185-1106A1BSYA4 | DIP White Female Header | Connector | 1X6P-2.54-8.5 | YXCON | http://www.seeedstudio.com/wiki/images/e/e3/3460540P1.pdf | 0.200 | 10 | 6 | 0.60 |  | http://www.seeedstudio.com/depot/OPLopen-parts-library-catalog-c-136_138/#3460540P1
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

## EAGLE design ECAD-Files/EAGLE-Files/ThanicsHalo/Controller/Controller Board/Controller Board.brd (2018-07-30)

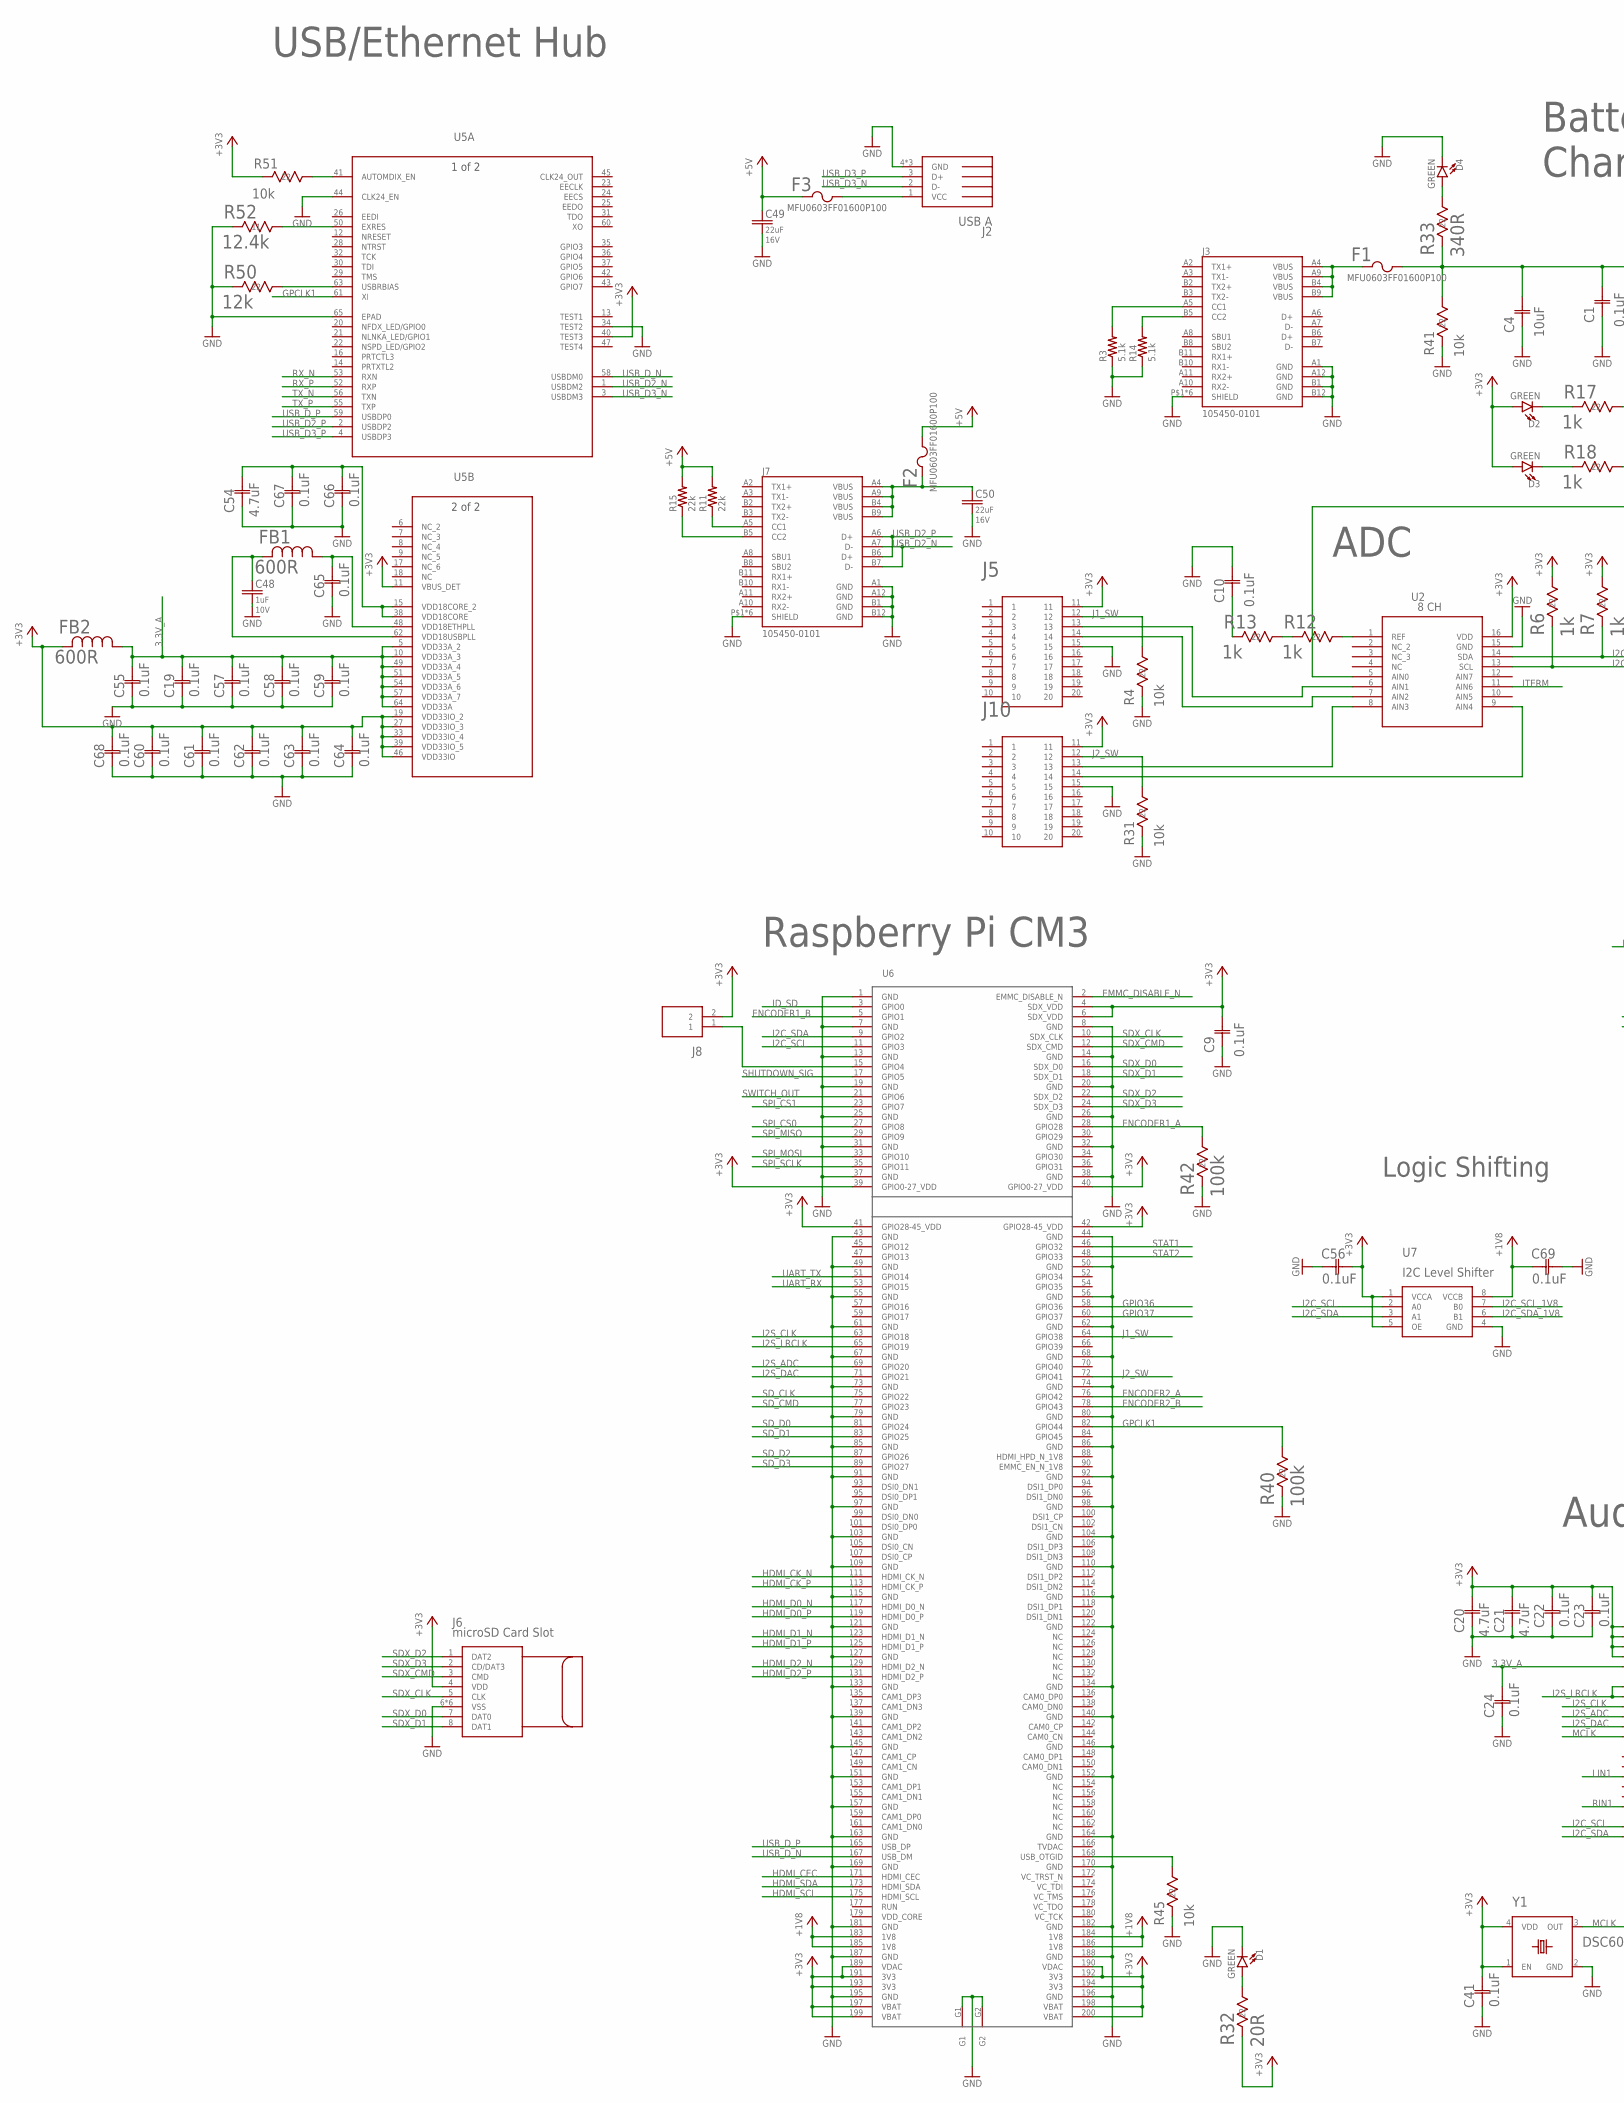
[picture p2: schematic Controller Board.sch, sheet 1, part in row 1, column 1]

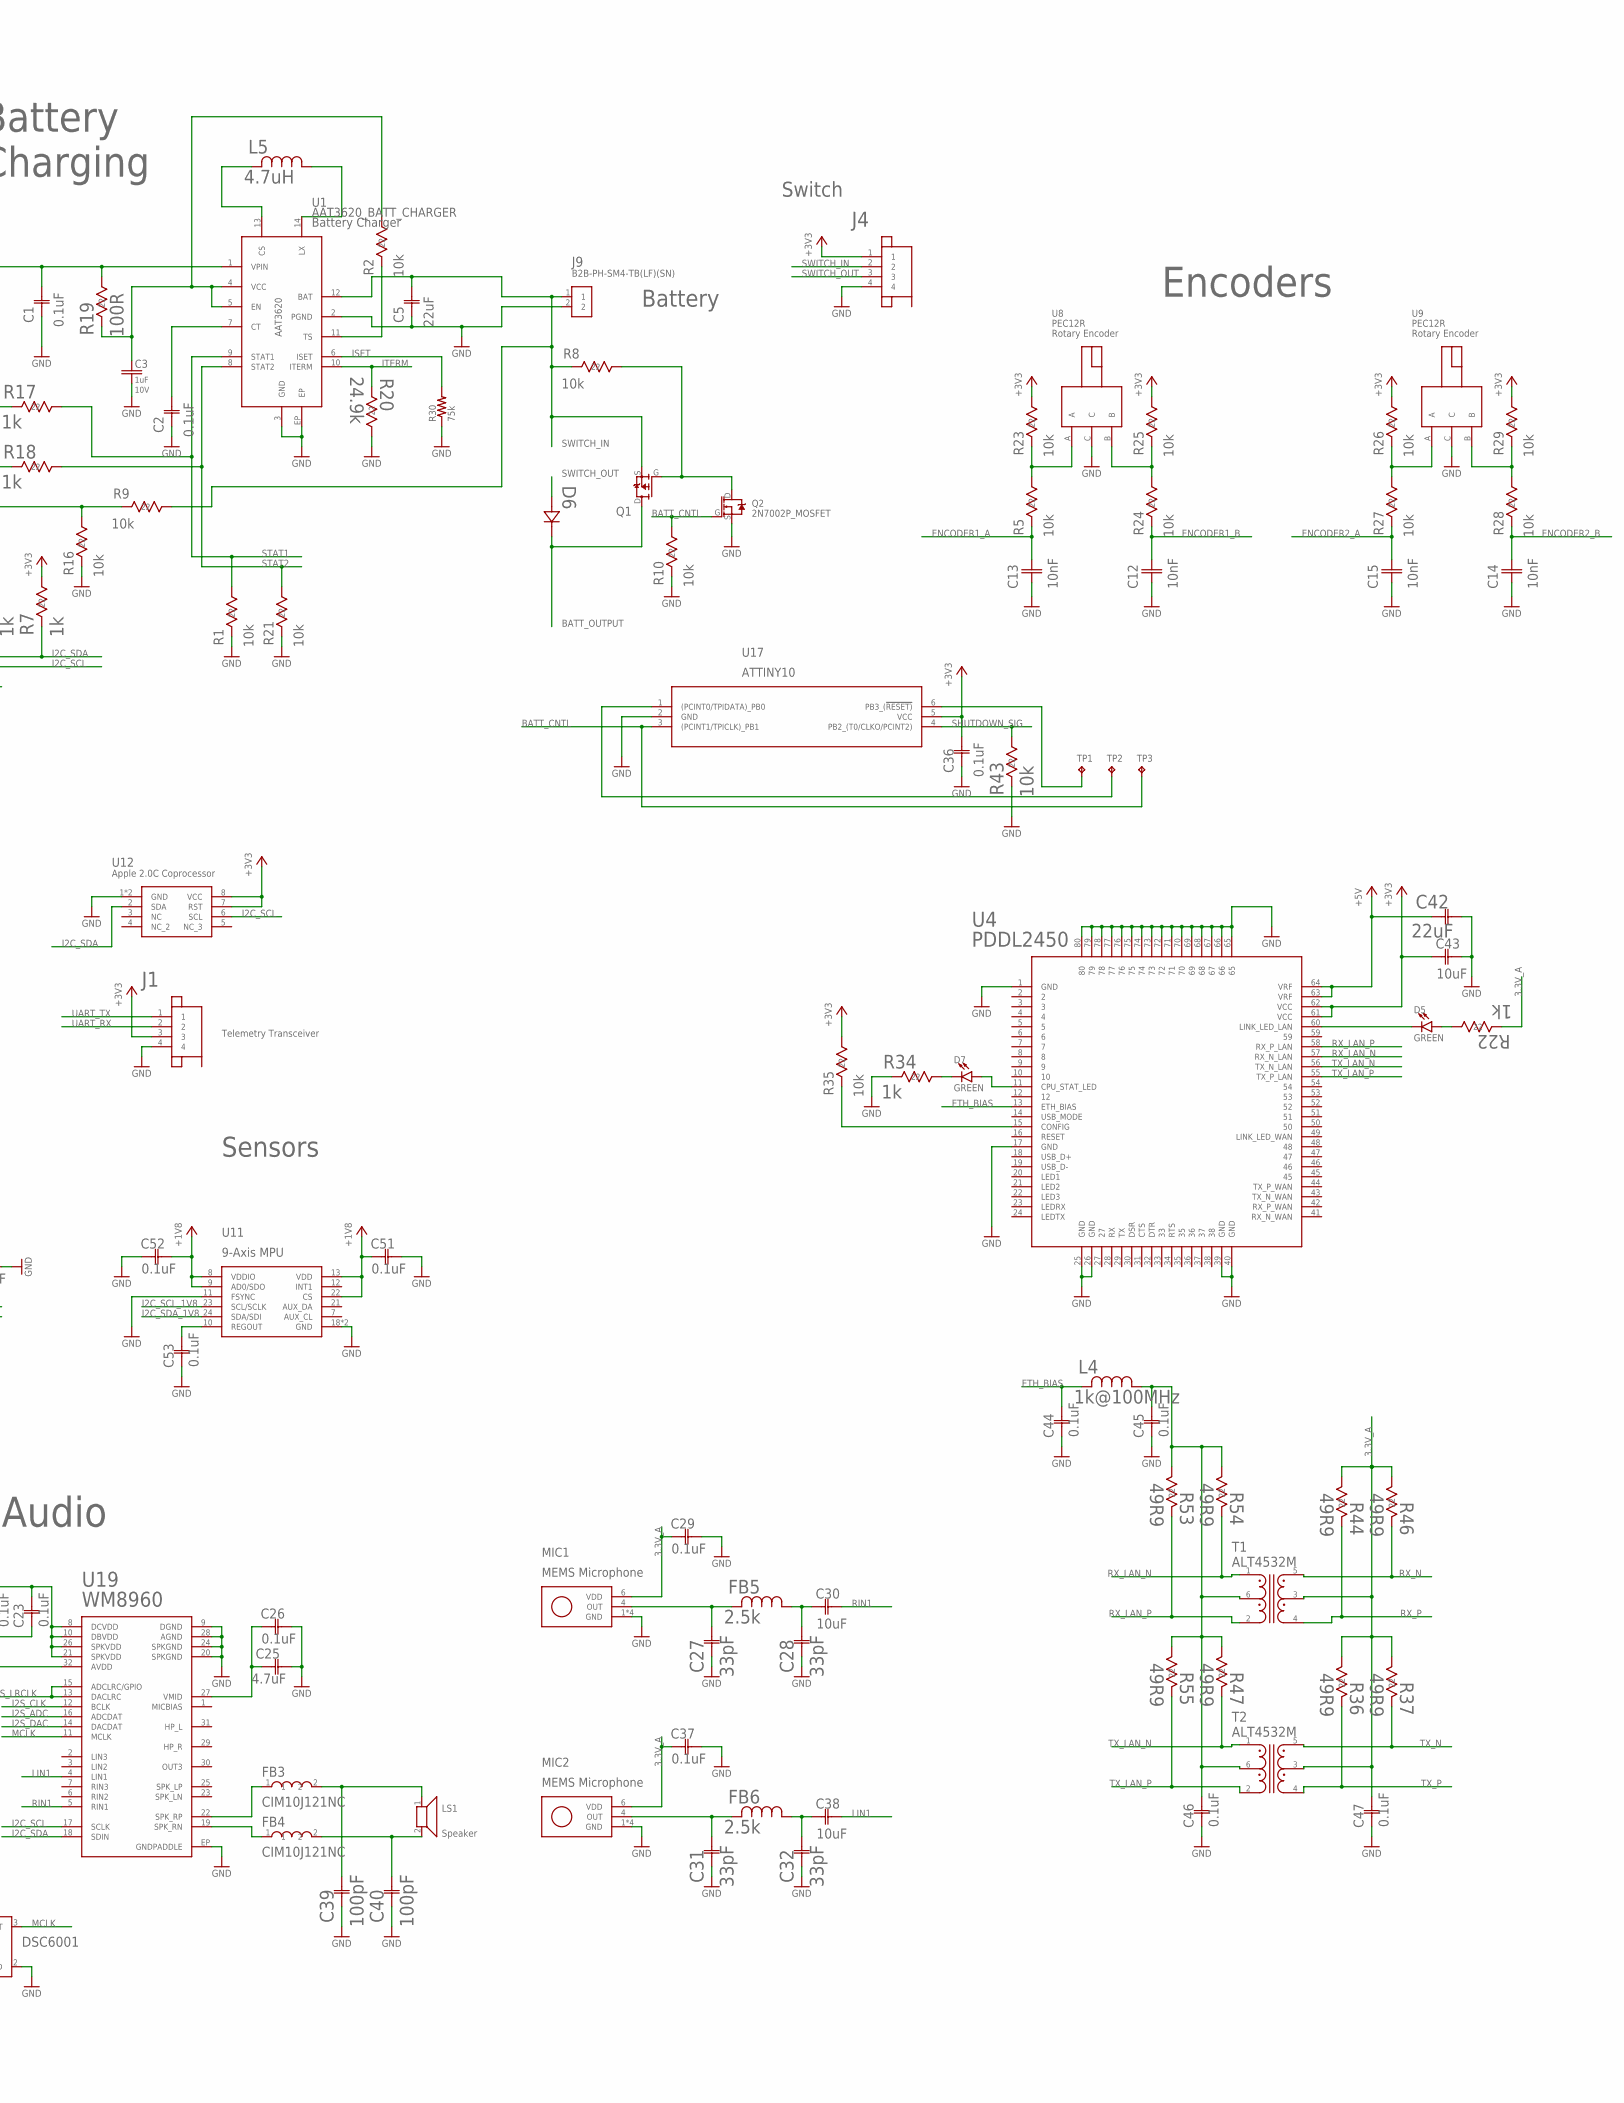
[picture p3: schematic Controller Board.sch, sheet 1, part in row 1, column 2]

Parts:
C1, C2, C9, C10, C36: 0.1uF; 0805
C3, C48: 1uF; C0402
C4, C30, C38, C43: 10uF; G-21
C5, C42: 22uF; G-21
C12, C13, C14, C15: 10nF; 0603_CAPACITOR
C19, C22, C23, C24, C26, C29, C37, C41, C44, C45, C46, C47, C51, C52, C53, C55, C56, C57, C58, C59, C60, C61, C62, C63, C64, C65, C66, C67, C68, C69: 0.1uF; 0402-M
C20, C21, C25, C54: 4.7uF; 0603-M
C27, C28, C31, C32: 33pF; G-155-M
C39, C40: 100pF; YAG_CC0402-M
C49, C50: 22uF; C0805
D1, D2, D3, D4, D5, D7: GREEN; LED-0603
D6: 1N4148W-7-FSOD123-M; SOD123-M
F1, F2, F3: MFU0603FF01600P100; FUS_VISHAY_MFU0603
FB1, FB2: 600R; IND_BLM18_0603-M
FB3, FB4: CIM10J121NC; 0603_CAPACITOR
FB5, FB6: 2.5k; IND_BLM18_0603-M
J1, J4: JST_SH_4POS
J2: USB_A_RECEPT
J3, J7: 105450-0101; MOLEX_105450-0101
J5, J10: EDGE_CONNECTOR_20POS
J6: MICROSD
J8: 2_PIN_CONNECTOR; XH_CONNECTOR
J9: B2B-PH-SM4-TB(LF)(SN)
L4: 1k@100MHz; IND_BLM18_0603-M
L5: 4.7uH; 1008
LS1: SP-1510; SPEAKER
MIC1, MIC2: SPH1642HT5H-1; SISONIC_MICROPHONE
Q1: DMP3099L; SOT-23_(TO-236AB)
Q2: 2N7002P_MOSFET; SOT-23_(TO-236AB)
R1, R2, R4, R5, R8, R9, R10, R16, R21, R23, R24, R25, R26, R27, R28, R29, R31, R35, R41, R45, R51: 10k; RC0603N-M
R3, R14: 5.1k; R0603
R6, R7, R12, R13, R17, R18, R22, R34: 1k; RC0603N-M
R11, R15: 22k; R0603
R19: 100R; RC0603N-M
R20: 24.9k; RC0402N-M
R30: 75k; R0603
R32: 20R; RC0603N-M
R33: 340R; RC0603N
R36, R37, R44, R46, R47, R53, R54, R55: 49R9; RC0402N-M
R40, R42: 100k; RC0603N-M
R43: 10k; RC0805N
R50: 12k; RC0402N-M
R52: 12.4k; YAG_R0402-M
T1, T2: ALT4532M; ALT4532
TP1, TP2, TP3: TPB2,54; B2,54
U1: AAT3620_BATT_CHARGER; AAT3620_TDFN
U2: 8 CH; 21-0055H_16-M
U4: PDDL2450; PDDL2450_SOCKET
U5: LAN9512-JZXQFN64_9X9MC-M; QFN64_9X9MC-M
U6: COMPUTE_MODULE; SO-DIMM
U7: FXMAR2102; 8-UMLP
U8, U9: PEC12R
U11: ICM-20948; QFN40P300X300X105-25N
U12: APPLE_2.0C_COPROCESSOR; PG-USON-8-1
U17: ATTINY10-TSHR6ST1-M; 6ST1-M
U19: WM8960; 32QFN
Y1: DSC6001; 4-VFLGA

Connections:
3.3V_A: C19.2, C24.2, C29.1, C37.1, C47.2, C55.2, C57.2, C58.2, C59.2, FB2.1, MIC1.6 (VDD), MIC2.6 (VDD), R22.2 (22), R36.1 (11), R37.1 (11), R44.1 (11), R46.1 (11), T1.3, T2.3, U5.5 (VDD33A_2), U5.10 (VDD33A_3), U5.49 (VDD33A_4), U5.51 (VDD33A_5), U5.54 (VDD33A_6), U5.57 (VDD33A_7), U5.64 (VDD33A), U19.32 (AVDD)
+1V8: C51.1, C52.2, C69.1, U6.183 (1V8), U6.184 (1V8), U6.185 (1V8), U6.186 (1V8), U7.8 (VCCB), U11.8 (VDDIO), U11.9 (AD0/SDO), U11.13 (VDD), U11.22 (CS); also elsewhere on the board
+3V3: C9.2, C20.2, C21.2, C22.2, C23.2, C36.2, C41.2, C43.1 (11), C56.2, C60.2, C61.2, C62.2, C63.2, C64.2, C68.2, D2.A, D3.A, FB2.2, J1.3, J4.1, J5.11, J6.4 (VDD), J8.2, J10.11, R6.1 (11), R7.1 (11), R23.1 (11), R25.1 (11), R26.1 (11), R29.1 (11), R32.2 (22), R35.1 (11), R51.2 (22), U2.16 (VDD), U4.61 (VCC), U4.62 (VCC), U5.11 (VBUS_DET), U5.19 (VDD33IO_2), U5.27 (VDD33IO_3), U5.33 (VDD33IO_4), U5.39 (VDD33IO_5), U5.40 (TEST3), U5.46 (VDD33IO), U6.4 (SDX_VDD), U6.6 (SDX_VDD), U6.39 (GPIO0-27_VDD), U6.40 (GPIO0-27_VDD), U6.41 (GPIO28-45_VDD), U6.42 (GPIO28-45_VDD), U6.189 (VDAC), U6.190 (VDAC), U6.191 (3V3), U6.192 (3V3), U6.193 (3V3), U6.194 (3V3), U6.197 (VBAT), U6.198 (VBAT), U6.199 (VBAT), U6.200 (VBAT), U7.1 (VCCA), U7.5 (OE), U12.7 (RST), U12.8 (VCC), U17.5 (VCC), U19.8 (DCVDD), U19.10 (DBVDD), U19.21 (SPKVDD), U19.26 (SPKVDD), Y1.1 (EN), Y1.4 (VDD); also elsewhere on the board
+5V: C42.1 (11), C49.1, F2.2, F3.1, R11.2, R15.2, U4.63 (VRF), U4.64 (VRF); also elsewhere on the board
BATT_CNTL: Q2.G, R10.1 (11), TP3.TP, U17.3 ((PCINT1/TPICLK)_PB1)
BATT_OUTPUT: D6.C (12), Q1.D; also elsewhere on the board
EMMC_DISABLE_N: U6.2 (EMMC_DISABLE_N)
ENCODER1_A: C13.2, R5.2 (22), R42.1 (11), U6.28 (GPIO28)
ENCODER1_B: C12.2, R24.2 (22), U6.5 (GPIO1)
ENCODER2_A: C15.2, R27.2 (22), U6.76 (GPIO42)
ENCODER2_B: C14.2, R28.2 (22), U6.78 (GPIO43)
ETH_BIAS: C44.2, L4.2, U4.13 (ETH_BIAS)
GND: C1.1, C2.1, C3.2, C4.1, C5.1, C9.1, C10.2, C12.1, C13.1, C14.1, C15.1, C19.1, C20.1, C21.1, C22.1, C23.1, C24.1, C25.2, C26.2, C27.1 (11), C28.1 (11), C29.2, C31.1 (11), C32.1 (11), C36.1, C37.2, C39.1 (11), C40.1 (11), C41.1, C42.2 (22), C43.2 (22), C44.1, C45.1, C46.1, C47.1, C48.2, C49.2, C50.2, C51.2, C52.1, C53.1, C54.1, C55.1, C56.1, C57.1, C58.1, C59.1, C60.1, C61.1, C62.1, C63.1, C64.1, C65.1, C66.1, C67.1, C68.1, C69.2, D1.C, D4.C, J1.4, J2.4 (GND), J2.5 (GND), J2.6 (GND), J3.A1 (GND), J3.A12 (GND), J3.B1 (GND), J3.B12 (GND), J3.P$1 (SHIELD), J3.P$2 (SHIELD), J3.P$3 (SHIELD), J3.P$4 (SHIELD), J3.P$5 (SHIELD), J3.P$6 (SHIELD), J4.4, J5.15, J6.6 (VSS), J6.9 (VSS), J6.10 (VSS), J6.11 (VSS), J6.12 (VSS), J6.13 (VSS), J7.A1 (GND), J7.A12 (GND), J7.B1 (GND), J7.B12 (GND), J7.P$1 (SHIELD), J7.P$2 (SHIELD), J7.P$3 (SHIELD), J7.P$4 (SHIELD), J7.P$5 (SHIELD), J7.P$6 (SHIELD), J9.2, J10.15, MIC1.1 (GND), MIC1.2 (GND), MIC1.3 (GND), MIC1.5 (GND), MIC2.1 (GND), MIC2.2 (GND), MIC2.3 (GND), MIC2.5 (GND), Q2.S, R1.2 (22), R3.1, R4.2 (22), R10.2 (22), R14.1, R16.2 (22), R20.1 (11), R21.2 (22), R30.1, R31.2 (22), R34.2 (22), R40.2 (22), R41.2 (22), R42.2 (22), R43.2 (22), R45.2 (22), R50.2 (22), R52.1 (11), U1.2 (PGND), U1.3 (GND), U1.EP, U2.15 (GND), U4.1 (GND), U4.17 (GND), U4.25 (GND), U4.26 (GND), U4.39 (GND), U4.40 (GND), U4.65, U4.66, U4.67, U4.68, U4.69, U4.70, U4.71, U4.72, U4.73, U4.74, U4.75, U4.76, U4.77, U4.78, U4.79, U4.80, U5.34 (TEST2), U5.44 (CLK24_EN), U5.65 (EPAD), U6.1 (GND), U6.7 (GND), U6.8 (GND), U6.13 (GND), U6.14 (GND), U6.19 (GND), U6.20 (GND), U6.25 (GND), U6.26 (GND), U6.31 (GND), U6.32 (GND), U6.37 (GND), U6.38 (GND), U6.43 (GND), U6.44 (GND), U6.49 (GND), U6.50 (GND), U6.55 (GND), U6.56 (GND), U6.61 (GND), U6.62 (GND), U6.67 (GND), U6.68 (GND), U6.73 (GND), U6.74 (GND), U6.79 (GND), U6.80 (GND), U6.85 (GND), U6.86 (GND), U6.91 (GND), U6.92 (GND), U6.97 (GND), U6.98 (GND), U6.103 (GND), U6.104 (GND), U6.109 (GND), U6.110 (GND), U6.115 (GND), U6.116 (GND), U6.121 (GND), U6.122 (GND), U6.127 (GND), U6.133 (GND), U6.134 (GND), U6.139 (GND), U6.140 (GND), U6.145 (GND), U6.146 (GND), U6.151 (GND), U6.152 (GND), U6.157 (GND), U6.163 (GND), U6.164 (GND), U6.169 (GND), U6.170 (GND), U6.181 (GND), U6.182 (GND), U6.187 (GND), U6.188 (GND), U6.195 (GND), U6.196 (GND), U6.G1, U6.G2, U7.4 (GND), U8.C, U9.C, U11.11 (FSYNC), U11.18 (GND), U11.20 (GND), U12.1 (GND), U12.9 (GND), U17.2 (GND), U19.9 (DGND), U19.20 (SPKGND), U19.24 (SPKGND), U19.28 (AGND), U19.EP (GNDPADDLE), Y1.2 (GND); also elsewhere on the board
GND2: D5.C, U4.60 (LINK_LED_LAN)
GPCLK1: R40.1 (11), U5.61 (XI), U6.82 (GPIO44)
GPIO36: U6.58 (GPIO36)
GPIO37: U6.60 (GPIO37)
HDMI_CEC: U6.171 (HDMI_CEC)
HDMI_CK_N: U6.111 (HDMI_CK_N)
HDMI_CK_P: U6.113 (HDMI_CK_P)
HDMI_D0_N: U6.117 (HDMI_D0_N)
HDMI_D0_P: U6.119 (HDMI_D0_P)
HDMI_D1_N: U6.123 (HDMI_D1_N)
HDMI_D1_P: U6.125 (HDMI_D1_P)
HDMI_D2_N: U6.129 (HDMI_D2_N)
HDMI_D2_P: U6.131 (HDMI_D2_P)
HDMI_SCL: U6.175 (HDMI_SCL)
HDMI_SDA: U6.173 (HDMI_SDA)
I2C_SCL: R6.2 (22), U2.13 (SCL), U6.11 (GPIO3), U7.2 (A0), U12.6 (SCL), U19.17 (SCLK)
I2C_SCL_1V8: U7.7 (B0), U11.23 (SCL/SCLK)
I2C_SDA: R7.2 (22), U2.14 (SDA), U6.9 (GPIO2), U7.3 (A1), U12.2 (SDA), U19.18 (SDIN)
I2C_SDA_1V8: U7.6 (B1), U11.24 (SDA/SDI)
I2S_ADC: U6.69 (GPIO20), U19.16 (ADCDAT)
I2S_CLK: U6.63 (GPIO18), U19.12 (BCLK)
I2S_DAC: U6.71 (GPIO21), U19.14 (DACDAT)
I2S_LRCLK: U6.65 (GPIO19), U19.13 (DACLRC), U19.15 (ADCLRC/GPIO)
ID_SD: U6.3 (GPIO0)
ISET: R30.2, U1.6 (ISET)
ITERM: R20.2 (22), U1.10 (ITERM), U2.11 (AIN6)
J1_SW: J5.12, R4.1 (11), U6.64 (GPIO38)
J2_SW: J10.12, R31.1 (11), U6.72 (GPIO41)
LIN1: C38.2 (22), U19.4 (LIN1)
MCLK: U19.11 (MCLK), Y1.3 (OUT)
unnamed: TP1.TP, U17.6 (PB3_(!RESET))
unnamed: C2.2, U1.7 (CT)
unnamed: L5.P$2 (2), U1.13 (CS)
unnamed: L5.P$1 (1), U1.14 (LX)
unnamed: C3.1, R2.1 (11), R19.2 (22), U1.4 (VCC), U1.5 (EN)
unnamed: C53.2, U11.10 (REGOUT)
unnamed: D4.A, R33.1 (11)
unnamed: D1.A, R32.1 (11)
unnamed: R2.2 (22), U1.11 (TS)
unnamed: C25.1, C26.1, U19.27 (VMID)
unnamed: D2.C, R17.2 (22)
unnamed: R12.1 (11), U2.1 (REF)
unnamed: J5.13, U2.6 (AIN1)
unnamed: J5.14, U2.7 (AIN2)
unnamed: J10.13, U2.8 (AIN3)
unnamed: J10.14, U2.9 (AIN4)
unnamed: C27.2 (22), FB5.2, MIC1.4 (OUT)
unnamed: D3.C, R18.2 (22)
unnamed: R12.2 (22), R13.1 (11)
unnamed: C10.1, R13.2 (22)
unnamed: R5.1 (11), R23.2 (22), U8.A
unnamed: C28.2 (22), C30.1 (11), FB5.1
unnamed: R24.1 (11), R25.2 (22), U8.B
unnamed: C31.2 (22), FB6.2, MIC2.4 (OUT)
unnamed: C32.2 (22), C38.1 (11), FB6.1
unnamed: R26.2 (22), R27.1 (11), U9.A
unnamed: R28.1 (11), R29.2 (22), U9.B
unnamed: R9.2 (22), R16.1 (11), U2.5 (AIN0)
unnamed: FB4.1, U19.19 (SPK_RN)
unnamed: FB3.1, U19.22 (SPK_RP)
unnamed: C39.2 (22), FB3.2, LS1.1
unnamed: C40.2 (22), FB4.2, LS1.2
unnamed: J3.B5 (CC2), R14.2
unnamed: F1.1, J3.A4 (VBUS), J3.A9 (VBUS), J3.B4 (VBUS), J3.B9 (VBUS)
unnamed: J3.A5 (CC1), R3.2
unnamed: J7.A5 (CC1), R11.1
unnamed: C50.1, F2.1, J7.A4 (VBUS), J7.A9 (VBUS), J7.B4 (VBUS), J7.B9 (VBUS)
unnamed: R45.1 (11), U6.168 (USB_OTGID)
unnamed: J8.1, U6.15 (GPIO4)
unnamed: R51.1 (11), U5.41 (AUTOMDIX_EN)
unnamed: R50.1 (11), U5.63 (USBRBIAS)
unnamed: Q1.G, Q2.D, R8.1 (11)
unnamed: C65.2, FB1.1, U5.48 (VDD18ETHPLL)
unnamed: C48.1, FB1.2, U5.62 (VDD18USBPLL)
unnamed: R52.2 (22), U5.50 (EXRES)
unnamed: C54.2, C66.2, C67.2, U5.15 (VDD18CORE_2), U5.38 (VDD18CORE)
unnamed: J7.B5 (CC2), R15.1
unnamed: D5.A, R22.1 (11)
unnamed: R35.2 (22), U4.15 (CONFIG)
unnamed: D7.A, U4.11 (CPU_STAT_LED)
unnamed: D7.C, R34.1 (11)
unnamed: C45.2, C46.2, L4.1, R47.1 (11), R53.1 (11), R54.1 (11), R55.1 (11), T1.6, T2.6
unnamed: F3.2, J2.1 (VCC)
PB0: TP2.TP, U17.1 ((PCINT0/TPIDATA)_PB0)
RIN1: C30.2 (22), U19.5 (RIN1)
RX_LAN_N: R54.2 (22), T1.1, U4.57 (RX_N_LAN)
RX_LAN_P: R53.2 (22), T1.2, U4.58 (RX_P_LAN)
RX_N: R46.2 (22), T1.5, U5.53 (RXN)
RX_P: R44.2 (22), T1.4, U5.52 (RXP)
SDX_CLK: J6.5 (CLK), U6.10 (SDX_CLK)
SDX_CMD: J6.3 (CMD), U6.12 (SDX_CMD)
SDX_D0: J6.7 (DAT0), U6.16 (SDX_D0)
SDX_D1: J6.8 (DAT1), U6.18 (SDX_D1)
SDX_D2: J6.1 (DAT2), U6.22 (SDX_D2)
SDX_D3: J6.2 (CD/DAT3), U6.24 (SDX_D3)
SD_CLK: U6.75 (GPIO22)
SD_CMD: U6.77 (GPIO23)
SD_D0: U6.81 (GPIO24)
SD_D1: U6.83 (GPIO25)
SD_D2: U6.87 (GPIO26)
SD_D3: U6.89 (GPIO27)
SHUTDOWN_SIG: R43.1 (11), U6.17 (GPIO5), U17.4 (PB2_(T0/CLKO/PCINT2))
SPI_CS0: U6.27 (GPIO8)
SPI_CS1: U6.23 (GPIO7)
SPI_MISO: U6.29 (GPIO9)
SPI_MOSI: U6.33 (GPIO10)
SPI_SCLK: U6.35 (GPIO11)
STAT1: R1.1 (11), R17.1 (11), U1.9 (STAT1), U6.46 (GPIO32)
STAT2: R18.1 (11), R21.1 (11), U1.8 (STAT2), U6.48 (GPIO33)
SWITCH_IN: C5.2, J4.2, J9.1, Q1.S, R8.2 (22), R9.1 (11), U1.12 (BAT)
SWITCH_OUT: D6.A (21), J4.3, U6.21 (GPIO6)
TX_LAN_N: R47.2 (22), T2.1, U4.56 (TX_N_LAN)
TX_LAN_P: R55.2 (22), T2.2, U4.55 (TX_P_LAN)
TX_N: R37.2 (22), T2.5, U5.56 (TXN)
TX_P: R36.2 (22), T2.4, U5.55 (TXP)
UART_RX: J1.2, U6.53 (GPIO15)
UART_TX: J1.1, U6.51 (GPIO14)
USB_5V: C1.2, C4.2, F1.2, R19.1 (11), R33.2 (22), R41.1 (11), U1.1 (VPIN)
USB_D2_N: J7.A7 (D-), J7.B7 (D-), U5.1 (USBDM2)
USB_D2_P: J7.A6 (D+), J7.B6 (D+), U5.2 (USBDP2)
USB_D3_N: J2.2 (D-), U5.3 (USBDM3)
USB_D3_P: J2.3 (D+), U5.4 (USBDP3)
USB_D_N: U5.58 (USBDM0), U6.167 (USB_DM)
USB_D_P: U5.59 (USBDP0), U6.165 (USB_DP)

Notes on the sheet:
Battery
Switch
Telemetry Transceiver
Battery Charging
USB/Ethernet Hub
Encoders
Audio
ADC
Raspberry Pi CM3
Sensors
Logic Shifting

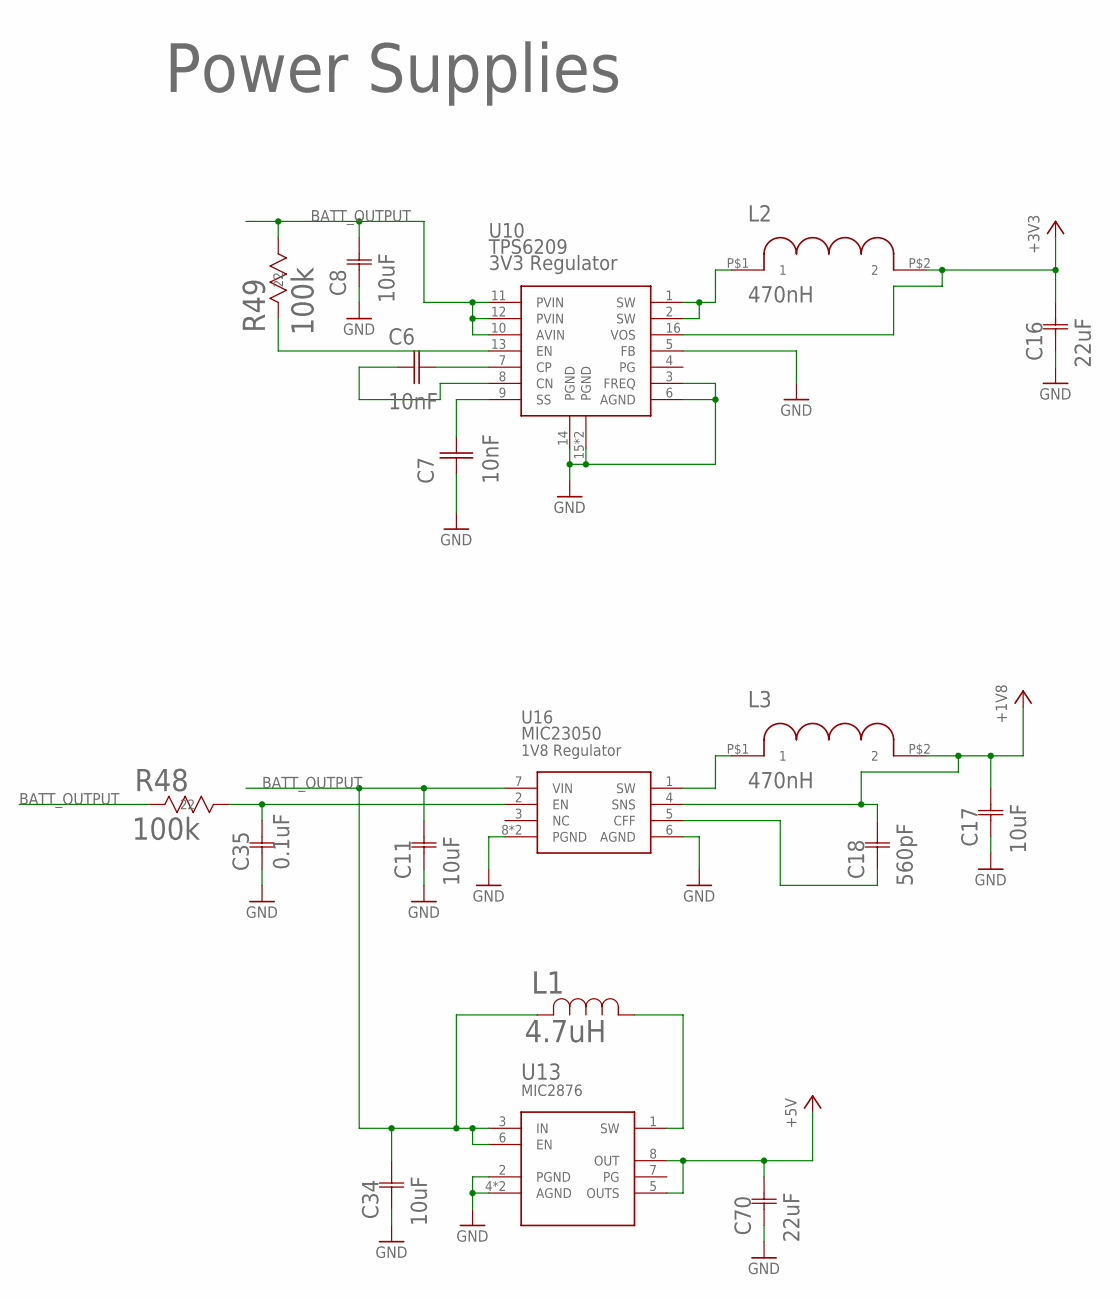
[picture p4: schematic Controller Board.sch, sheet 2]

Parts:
C6, C7: 10nF; 0603_CAPACITOR
C8, C11, C17, C34: 10uF; G-21
C16, C70: 22uF; G-21
C18: 560pF; CC0402N-M
C35: 0.1uF; 0402-M
L1: 4.7uH; 1008
L2, L3: 470nH; 470NH_INDUCTOR
R48, R49: 100k; RC0603N-M
U10: TPS6209; VQFN16
U13: MIC2876UDFN-8; UDFN8
U16: MIC23050; MLF(ML)_8PIN

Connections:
+1V8: C17.2, C18.2, L3.P$2 (2), U16.4 (SNS); also elsewhere on the board
+3V3: C16.2, L2.P$2 (2), U10.16 (VOS); also elsewhere on the board
+5V: C70.2, U13.5 (OUTS), U13.8 (OUT); also elsewhere on the board
BATT_OUTPUT: C8.2, C11.2, C34.2, L1.P$2 (2), R48.2 (22), R49.1 (11), U10.10 (AVIN), U10.11 (PVIN), U10.12 (PVIN), U13.3 (IN), U13.6 (EN), U16.7 (VIN); also elsewhere on the board
GND: C7.1, C8.1, C11.1, C16.1, C17.1, C34.1, C35.1, C70.1, U10.3 (FREQ), U10.5 (FB), U10.6 (AGND), U10.14 (PGND), U10.15 (PGND), U10.17 (PGND), U13.2 (PGND), U13.4 (AGND), U13.EP (AGND), U16.6 (AGND), U16.8 (PGND), U16.EP (PGND); also elsewhere on the board
unnamed: R49.2 (22), U10.13 (EN)
unnamed: C35.2, R48.1 (11), U16.2 (EN)
unnamed: C6.2, U10.7 (CP)
unnamed: C6.1, U10.8 (CN)
unnamed: C7.2, U10.9 (SS)
unnamed: L2.P$1 (1), U10.1 (SW), U10.2 (SW)
unnamed: L3.P$1 (1), U16.1 (SW)
unnamed: C18.1, U16.5 (CFF)
unnamed: L1.P$1 (1), U13.1 (SW)

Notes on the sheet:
Power Supplies

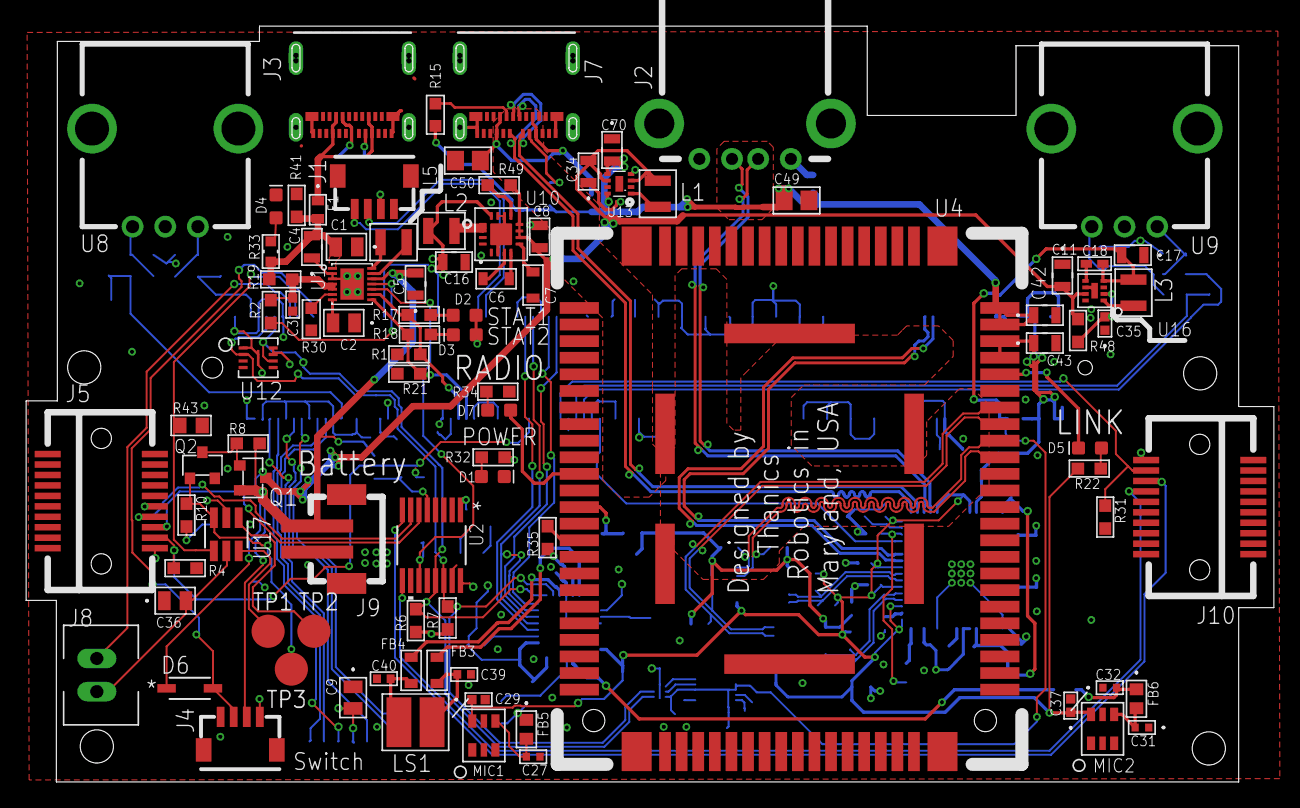
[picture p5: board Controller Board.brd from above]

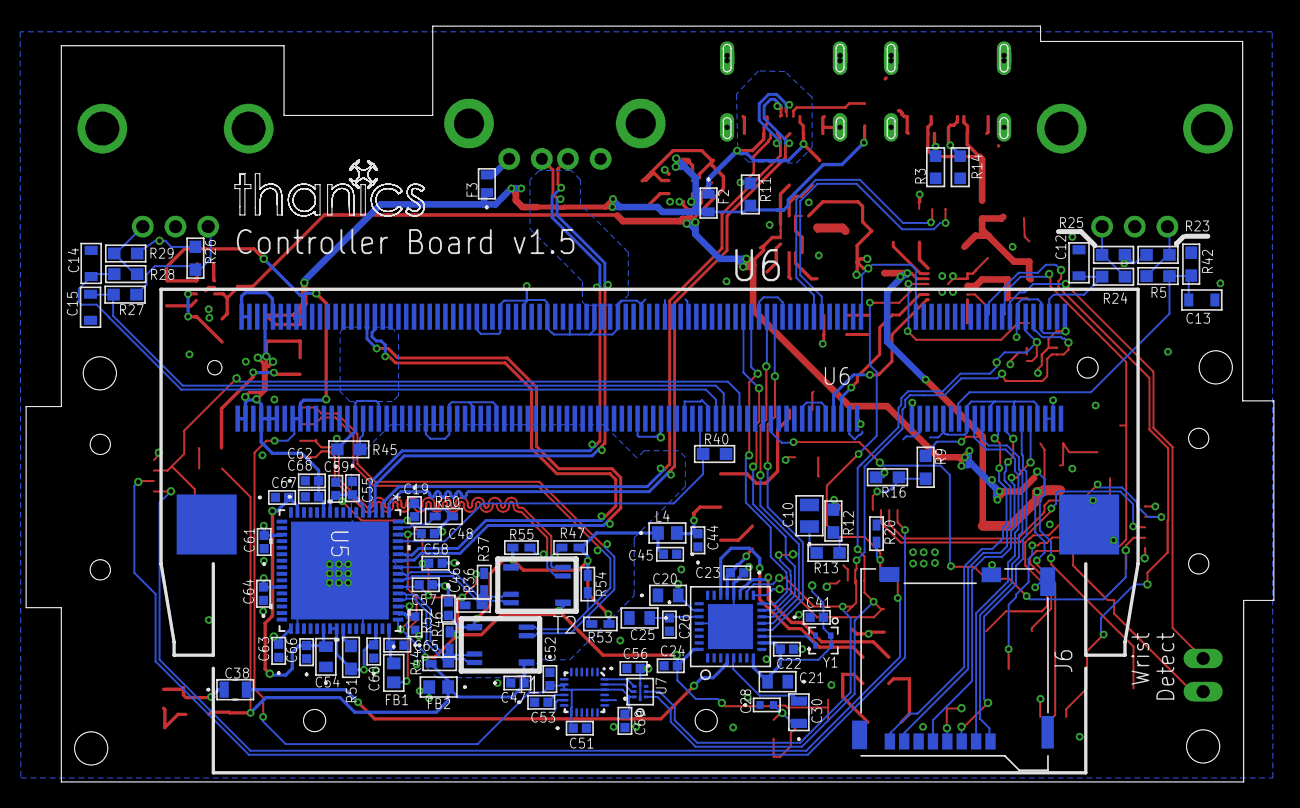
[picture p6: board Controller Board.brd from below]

Board: 4 copper layers, 95.5 x 57.8 mm, 179 parts (85 on the bottom side), 120 nets.

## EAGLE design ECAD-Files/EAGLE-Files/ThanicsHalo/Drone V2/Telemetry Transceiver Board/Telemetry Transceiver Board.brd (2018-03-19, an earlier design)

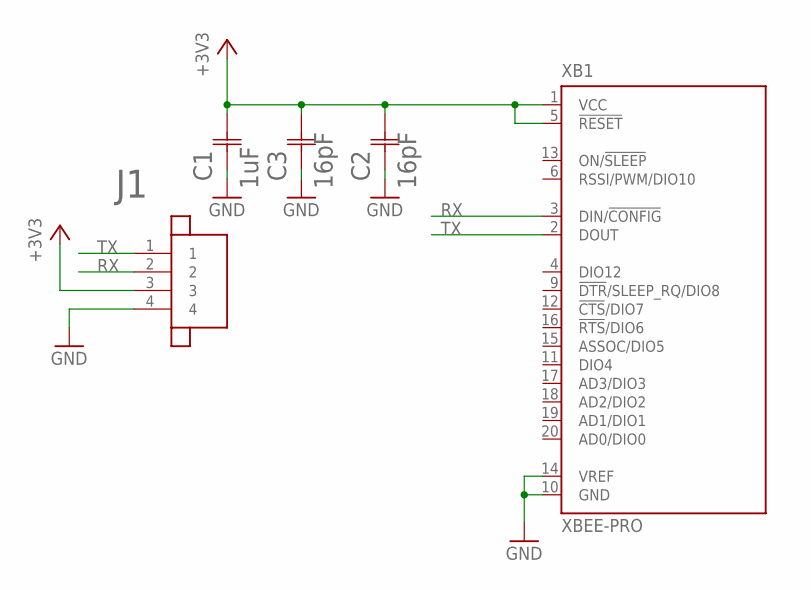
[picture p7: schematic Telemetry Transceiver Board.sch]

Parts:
C1: 1uF; YAG_CC0805
C2, C3: 16pF; G-155-M
J1: JST_SH_4POS
XB1: XBEE-PRO

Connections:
+3V3: C1.2 (22), C2.2 (22), C3.2 (22), J1.3, XB1.1 (VCC), XB1.5 (!RESET)
GND: C1.1 (11), C2.1 (11), C3.1 (11), J1.4, XB1.10 (GND), XB1.14 (VREF)
RX: J1.2, XB1.3 (DIN/!CONFIG)
TX: J1.1, XB1.2 (DOUT)

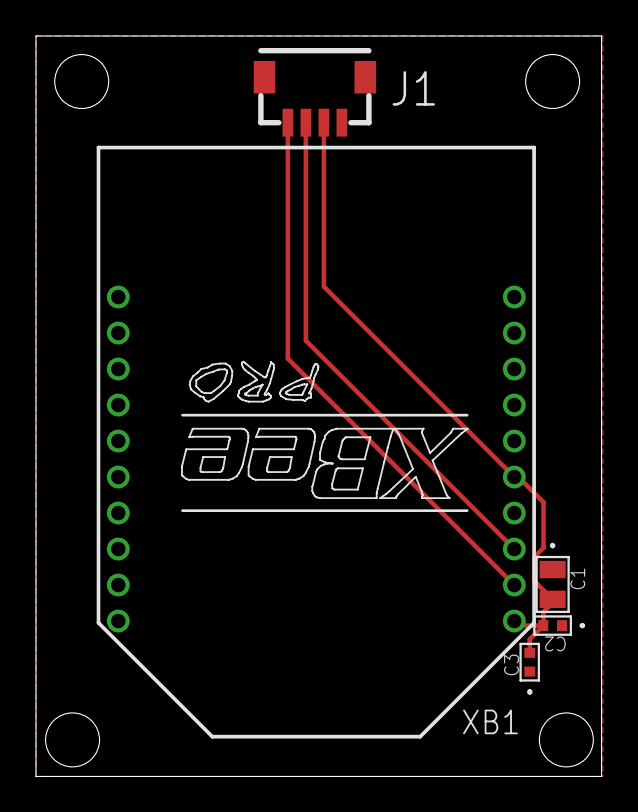
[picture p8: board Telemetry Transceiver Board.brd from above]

Board: 2 copper layers, 31.4 x 41.1 mm, 5 parts (0 on the bottom side), 4 nets.

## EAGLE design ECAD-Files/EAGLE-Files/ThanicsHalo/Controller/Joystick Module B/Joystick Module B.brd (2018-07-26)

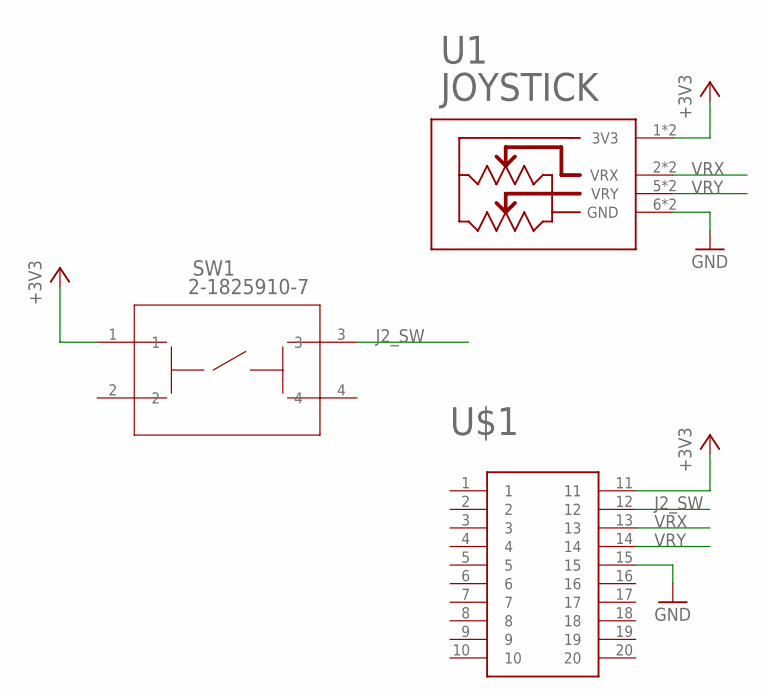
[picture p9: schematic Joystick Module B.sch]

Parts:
SW1: 2-1825910-7; SW4_1825910-G
U1: 27800-JOYSTICK
U$1: EDGE_CONNECTOR_20POS_CONTACTS

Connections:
+3V3: SW1.1, U1.1 (3V3), U1.3 (3V3), U$1.11
GND: U1.6 (GND), U1.8 (GND), U$1.15
J2_SW: SW1.3, U$1.12
VRX: U1.2 (VRX), U1.4 (VRX), U$1.13
VRY: U1.5 (VRY), U1.7 (VRY), U$1.14

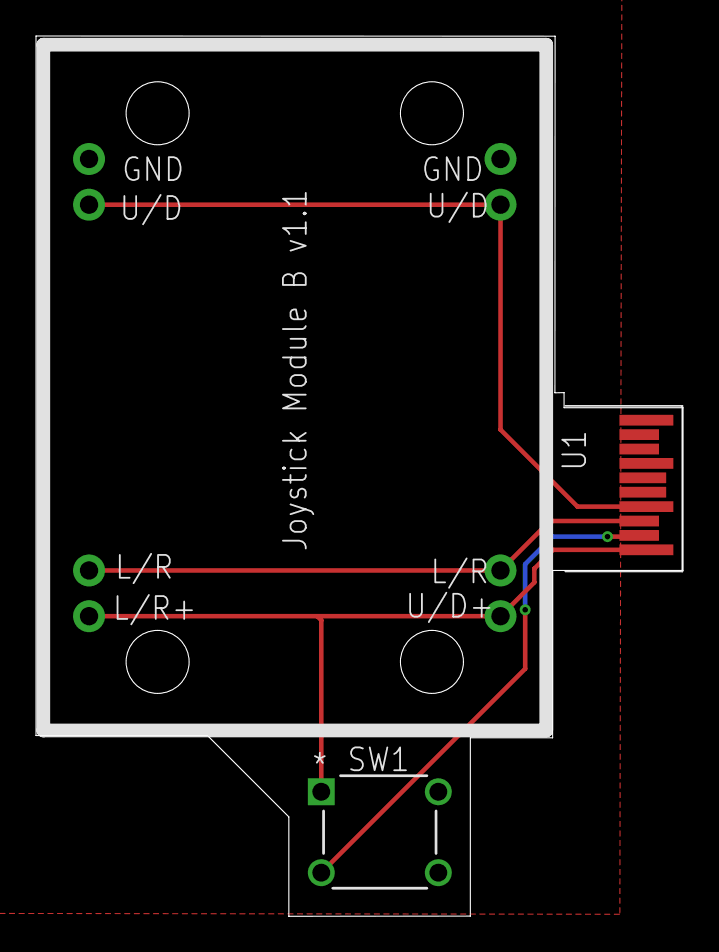
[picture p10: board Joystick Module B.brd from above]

Board: 2 copper layers, 35.9 x 48.9 mm, 3 parts (0 on the bottom side), 5 nets.

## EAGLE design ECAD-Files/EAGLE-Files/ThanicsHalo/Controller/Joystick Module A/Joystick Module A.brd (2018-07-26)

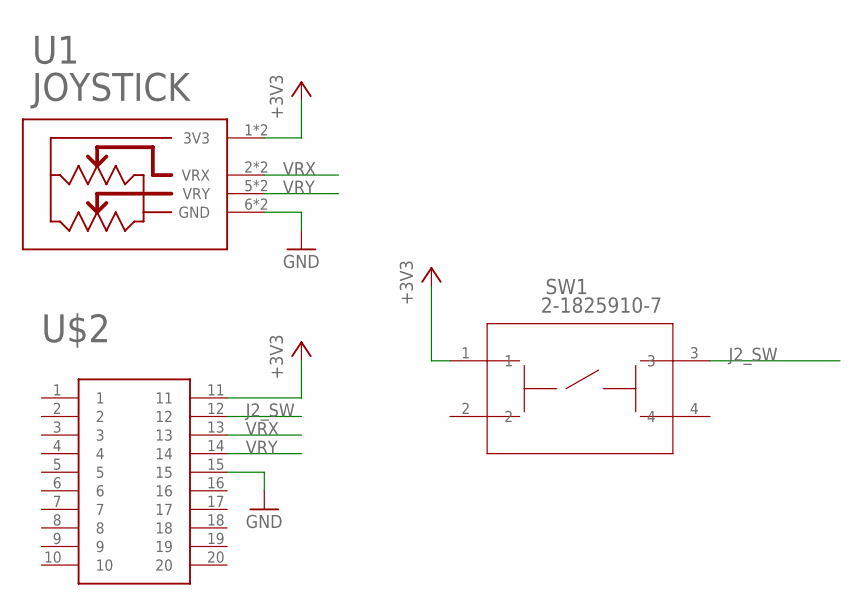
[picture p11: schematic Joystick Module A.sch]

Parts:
SW1: 2-1825910-7; SW4_1825910-G
U1: 27800-JOYSTICK
U$2: EDGE_CONNECTOR_20POS_CONTACTS

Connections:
+3V3: SW1.1, U1.1 (3V3), U1.3 (3V3), U$2.11
GND: U1.6 (GND), U1.8 (GND), U$2.15
J2_SW: SW1.3, U$2.12
VRX: U1.2 (VRX), U1.4 (VRX), U$2.13
VRY: U1.5 (VRY), U1.7 (VRY), U$2.14

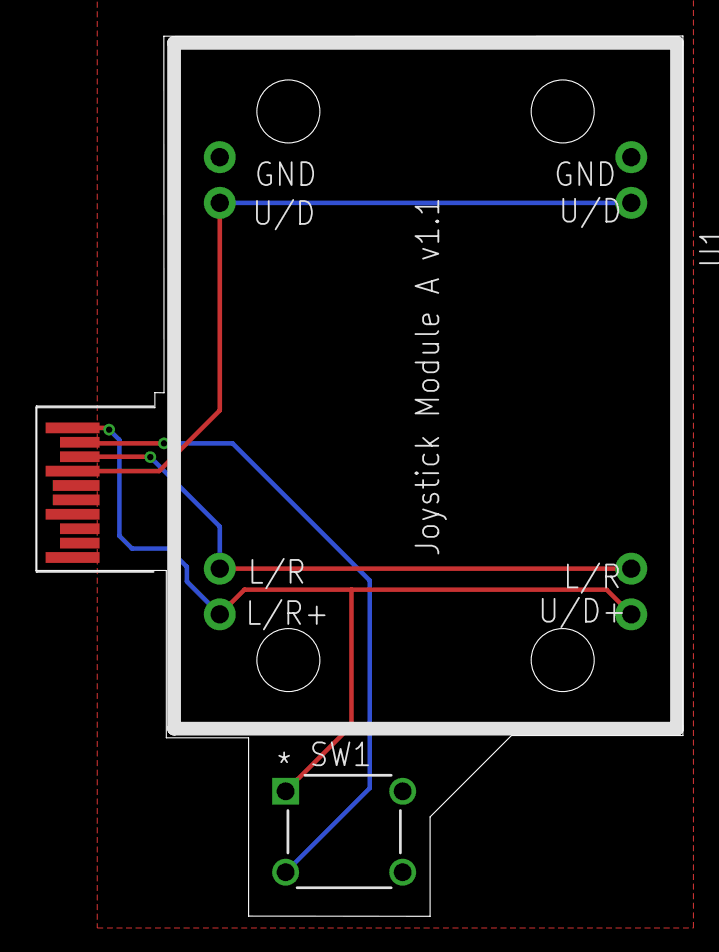
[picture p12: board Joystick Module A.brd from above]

Board: 2 copper layers, 35.9 x 48.9 mm, 3 parts (0 on the bottom side), 5 nets.

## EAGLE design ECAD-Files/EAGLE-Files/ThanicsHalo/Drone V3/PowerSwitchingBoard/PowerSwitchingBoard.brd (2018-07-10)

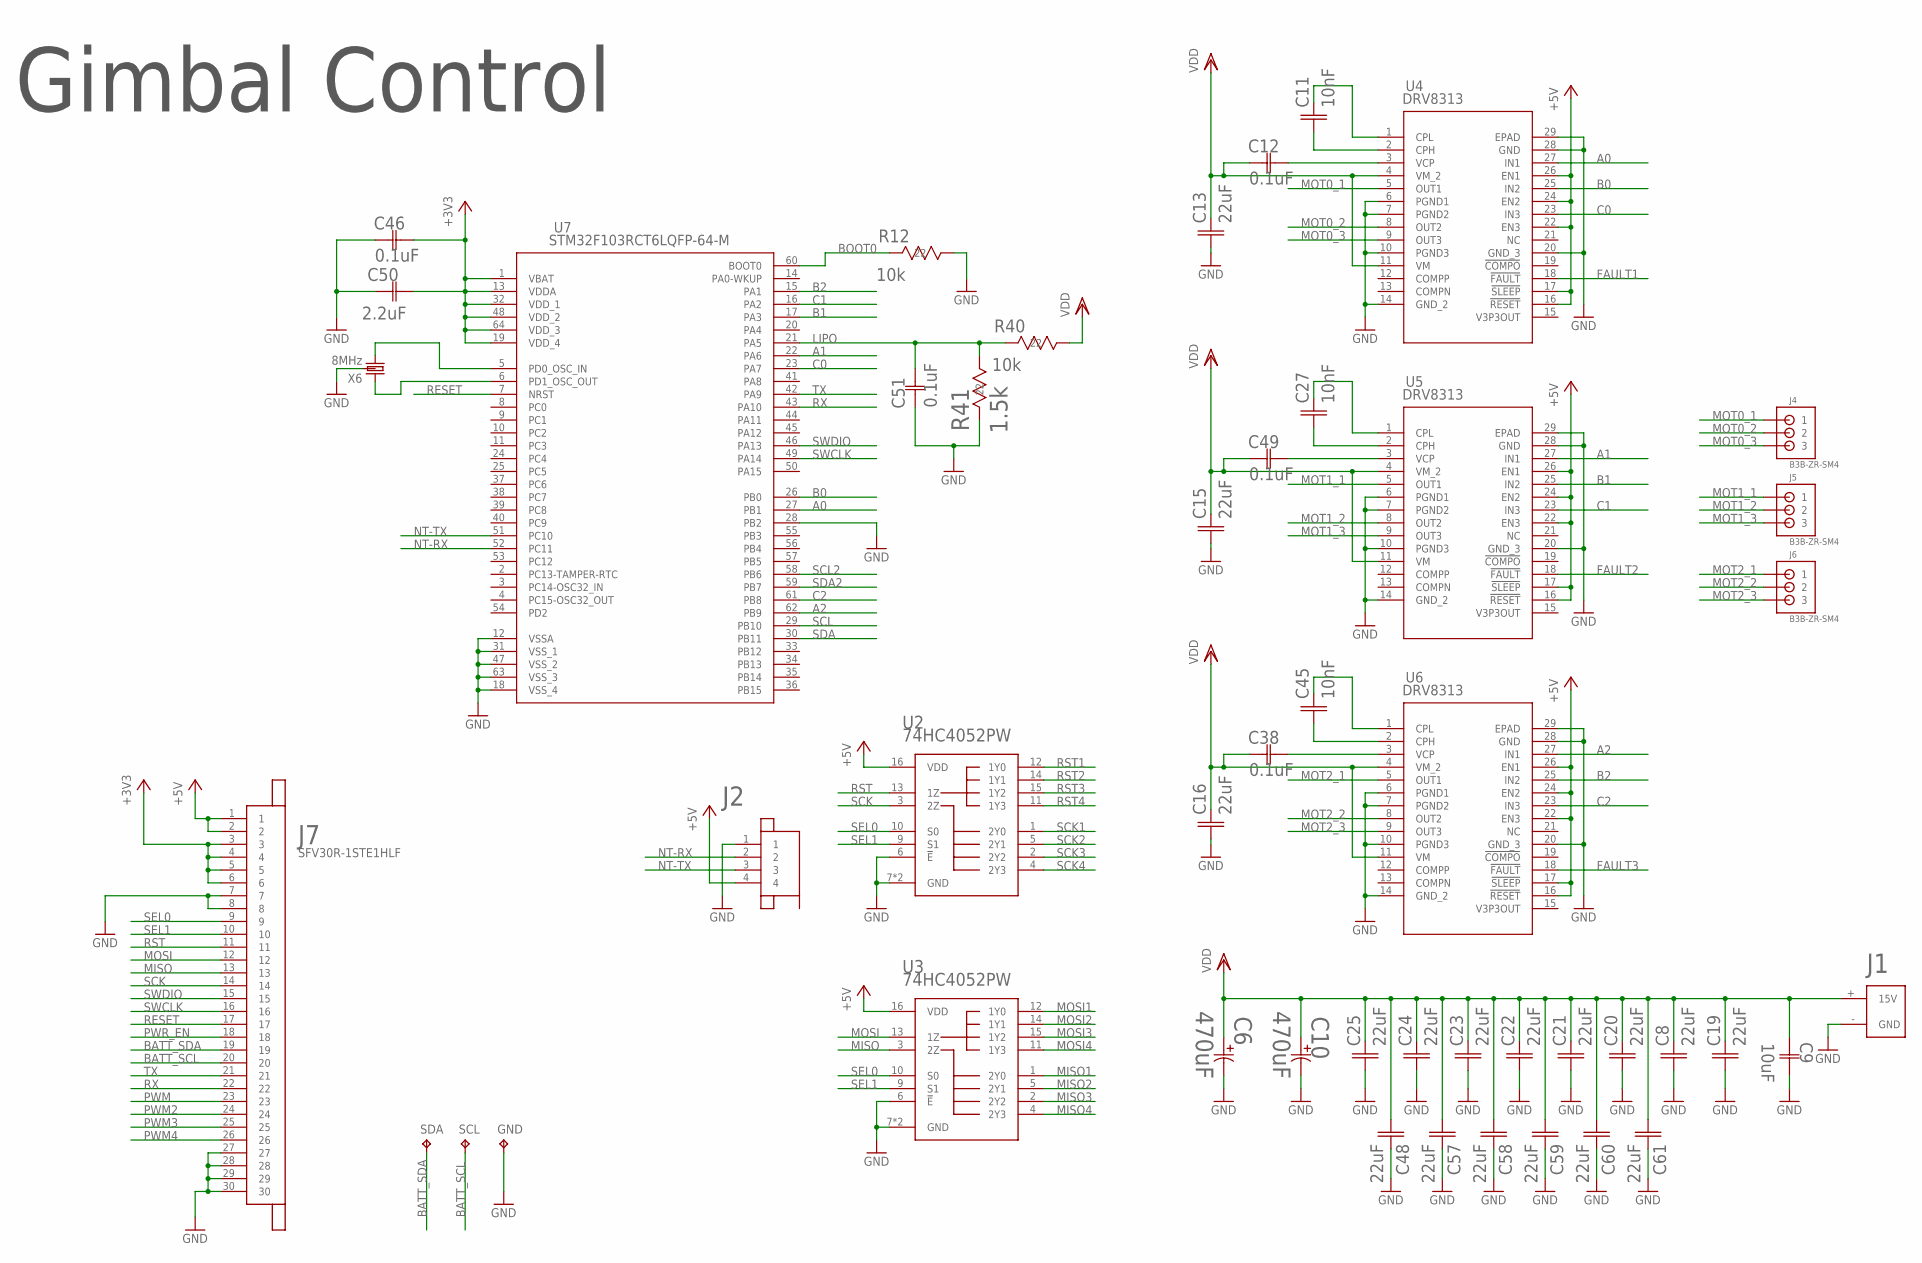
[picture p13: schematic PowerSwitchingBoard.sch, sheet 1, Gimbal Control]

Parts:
C6, C10: 470uF; PCAP_10X10-ELECT-M
C8, C13, C15, C16, C19, C20, C21, C22, C23, C24, C25, C48, C57, C58, C59, C60, C61: 22uF; 1210_CAPACITOR
C9: 10uF; G-21
C11, C27, C45: 10nF; 0603_CAPACITOR
C12, C38, C46, C49, C51: 0.1uF; 0402-M
C50: 2.2uF; G-188-M
GND: TPTP20SQ; TP20SQ
J1: ESC_CONTACTS; XT60_CONNECTOR
J2: JST_SH_4POS
J4, J5, J6: B3B-ZR-SM4
J7: SFV30R-1STE1HLF
R12, R40: 10k; RC0603N-M
R41: 1.5k; RC0603N-M
SCL: TPTP20SQ; TP20SQ
SDA: TPTP20SQ; TP20SQ
U2, U3: 74HC4052PW; TSSOP16
U4, U5, U6: DRV8313; PWP28_5P18X3P1-M
U7: STM32F103RCT6LQFP-64-M; LQFP-64-M
X6: 8MHz; 3-SMD

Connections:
+3V3: C46.2, C50.2 (22), J7.3, J7.4, J7.5, J7.6, U7.1 (VBAT), U7.13 (VDDA), U7.19 (VDD_4), U7.32 (VDD_1), U7.48 (VDD_2), U7.64 (VDD_3); also elsewhere on the board
+5V: J2.4, J7.1, J7.2, U2.16 (VDD), U3.16 (VDD), U4.16 (!RESET), U4.17 (!SLEEP), U4.22 (EN3), U4.24 (EN2), U4.26 (EN1), U5.16 (!RESET), U5.17 (!SLEEP), U5.22 (EN3), U5.24 (EN2), U5.26 (EN1), U6.16 (!RESET), U6.17 (!SLEEP), U6.22 (EN3), U6.24 (EN2), U6.26 (EN1); also elsewhere on the board
A0: U4.27 (IN1), U7.27 (PB1)
A1: U5.27 (IN1), U7.22 (PA6)
A2: U6.27 (IN1), U7.62 (PB9)
B0: U4.25 (IN2), U7.26 (PB0)
B1: U5.25 (IN2), U7.17 (PA3)
B2: U6.25 (IN2), U7.15 (PA1)
BATT_SCL: J7.20, SCL.TP
BATT_SDA: J7.19, SDA.TP
BOOT0: R12.2 (22), U7.60 (BOOT0)
C0: U4.23 (IN3), U7.23 (PA7)
C1: U5.23 (IN3), U7.16 (PA2)
C2: U6.23 (IN3), U7.61 (PB8)
FAULT1: U4.18 (!FAULT)
FAULT2: U5.18 (!FAULT)
FAULT3: U6.18 (!FAULT)
GND: C6.2 (22), C8.1, C9.2 (22), C10.2 (22), C13.1, C15.1, C16.1, C19.1, C20.1, C21.1, C22.1, C23.1, C24.1, C25.1, C46.1, C48.2, C50.1 (11), C51.1, C57.2, C58.2, C59.2, C60.2, C61.2, GND.TP, J1.- (GND), J2.1, J7.7, J7.8, J7.27, J7.28, J7.29, J7.30, R12.1 (11), R41.2 (22), U2.6 (!E), U2.7 (GND), U2.8 (GND), U3.6 (!E), U3.7 (GND), U3.8 (GND), U4.6 (PGND1), U4.7 (PGND2), U4.10 (PGND3), U4.14 (GND_2), U4.20 (GND_3), U4.28 (GND), U4.29 (EPAD), U5.6 (PGND1), U5.7 (PGND2), U5.10 (PGND3), U5.14 (GND_2), U5.20 (GND_3), U5.28 (GND), U5.29 (EPAD), U6.6 (PGND1), U6.7 (PGND2), U6.10 (PGND3), U6.14 (GND_2), U6.20 (GND_3), U6.28 (GND), U6.29 (EPAD), U7.12 (VSSA), U7.18 (VSS_4), U7.28 (PB2), U7.31 (VSS_1), U7.47 (VSS_2), U7.63 (VSS_3), X6.2 (GND); also elsewhere on the board
LIPO: C51.2, R40.2 (22), R41.1 (11), U7.21 (PA5)
MISO: J7.13, U3.3 (2Z)
MISO1: U3.1 (2Y0); also elsewhere on the board
MISO2: U3.5 (2Y1); also elsewhere on the board
MISO3: U3.2 (2Y2); also elsewhere on the board
MISO4: U3.4 (2Y3); also elsewhere on the board
MOSI: J7.12, U3.13 (1Z)
MOSI1: U3.12 (1Y0); also elsewhere on the board
MOSI2: U3.14 (1Y1); also elsewhere on the board
MOSI3: U3.15 (1Y2); also elsewhere on the board
MOSI4: U3.11 (1Y3); also elsewhere on the board
MOT0_1: J4.1, U4.5 (OUT1)
MOT0_2: J4.2, U4.8 (OUT2)
MOT0_3: J4.3, U4.9 (OUT3)
MOT1_1: J5.1, U5.5 (OUT1)
MOT1_2: J5.2, U5.8 (OUT2)
MOT1_3: J5.3, U5.9 (OUT3)
MOT2_1: J6.1, U6.5 (OUT1)
MOT2_2: J6.2, U6.8 (OUT2)
MOT2_3: J6.3, U6.9 (OUT3)
unnamed: C11.1, U4.2 (CPH)
unnamed: C11.2, U4.1 (CPL)
unnamed: C27.1, U5.2 (CPH)
unnamed: C27.2, U5.1 (CPL)
unnamed: C49.2, U5.3 (VCP)
unnamed: C45.1, U6.2 (CPH)
unnamed: C45.2, U6.1 (CPL)
unnamed: C38.2, U6.3 (VCP)
unnamed: U7.5 (PD0_OSC_IN), X6.3 (2)
unnamed: C12.2, U4.3 (VCP)
unnamed: U7.6 (PD1_OSC_OUT), X6.1
NT-RX: J2.2, U7.52 (PC11)
NT-TX: J2.3, U7.51 (PC10)
PWM: J7.23; also elsewhere on the board
PWM2: J7.24; also elsewhere on the board
PWM3: J7.25; also elsewhere on the board
PWM4: J7.26; also elsewhere on the board
PWR_EN: J7.18; also elsewhere on the board
RESET: J7.17, U7.7 (NRST)
RST: J7.11, U2.13 (1Z)
RST1: U2.12 (1Y0); also elsewhere on the board
RST2: U2.14 (1Y1); also elsewhere on the board
RST3: U2.15 (1Y2); also elsewhere on the board
RST4: U2.11 (1Y3); also elsewhere on the board
RX: J7.22, U7.43 (PA10)
SCK: J7.14, U2.3 (2Z)
SCK1: U2.1 (2Y0); also elsewhere on the board
SCK2: U2.5 (2Y1); also elsewhere on the board
SCK3: U2.2 (2Y2); also elsewhere on the board
SCK4: U2.4 (2Y3); also elsewhere on the board
SCL: U7.29 (PB10)
SCL2: U7.58 (PB6)
SDA: U7.30 (PB11)
SDA2: U7.59 (PB7)
SEL0: J7.9, U2.10 (S0), U3.10 (S0)
SEL1: J7.10, U2.9 (S1), U3.9 (S1)
SWCLK: J7.16, U7.49 (PA14)
SWDIO: J7.15, U7.46 (PA13)
TX: J7.21, U7.42 (PA9)
VDD: C6.1 (11), C8.2, C9.1 (11), C10.1 (11), C12.1, C13.2, C15.2, C16.2, C19.2, C20.2, C21.2, C22.2, C23.2, C24.2, C25.2, C38.1, C48.1, C49.1, C57.1, C58.1, C59.1, C60.1, C61.1, J1.+ (15V), R40.1 (11), U4.4 (VM_2), U4.11 (VM), U5.4 (VM_2), U5.11 (VM), U6.4 (VM_2), U6.11 (VM); also elsewhere on the board

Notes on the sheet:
Gimbal Control


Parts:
C33, C34, C35: 0.1uF (50V); 0402-M
C36, C62, C65, C66: 0.1uF; 0402-M
C37: 2.2uF; G-188-M
D4, D5, D6: 1N4148; SOD123-M
JP4: JUMPER-SMT_2_NO_NO-SILK; SMT-JUMPER_2_NO_NO-SILK
Q28, Q31, Q34: 500mA/300V; SOT23-3
Q29, Q30, Q32, Q33, Q35, Q36: IRLR8726; DPAK
R92, R93, R99, R104, R117, R118: 10k; RC0603N-M
R94, R100, R105: 2.2k; RC0603N-M
R95, R101, R106, R114, R115, R116: 4.7k; RC0603N-M
R96, R109, R110, R111, R112, R113: 47k; RC0603N-M
R97, R98, R102, R103, R107, R108: 100R; RC0603N-M
U9: MEGA8-AI; TQFP32-08
X4: 16MHz; 3-SMD

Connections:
+5V: C37.2 (22), C62.1, C66.2, R93.2 (22), U9.4 (VCC), U9.6 (VCC), U9.18 (AVCC); also elsewhere on the board
AHIN2: R95.2 (22), U9.27 (PC4(ADC4/SDA))
ALIN2: R92.1 (11), R98.2 (22), U9.30 (PD0(RXD))
AOUT2: C33.2, Q29.3 (S), Q30.2 (D), R113.1 (11)
A_SENSE2: R110.1 (11), R113.2 (22), R114.1 (11), U9.24 (PC1(ADC1))
BHIN2: R101.2 (22), U9.31 (PD1(TXD))
BLIN2: R99.1 (11), R103.2 (22), U9.28 (PC5(ADC5/SCL))
BOUT2: C34.2, Q32.3 (S), Q33.2 (D), R112.1 (11)
B_SENSE2: R109.1 (11), R112.2 (22), R115.1 (11), U9.23 (PC0(ADC0))
CHIN2: R106.2 (22), U9.1 (PD3(INT1))
CLIN2: R104.1 (11), R108.2 (22), U9.9 (PD5(T1))
COUT2: C35.2, Q35.3 (S), Q36.2 (D), R111.1 (11)
C_SENSE2: R96.1 (11), R111.2 (22), R116.1 (11), U9.22 (ADC7)
GND: C36.1, C37.1 (11), C62.2, C65.2, C66.1, JP4.2, Q28.2 (E), Q30.3 (S), Q31.2 (E), Q33.3 (S), Q34.2 (E), Q36.3 (S), R92.2 (22), R99.2 (22), R104.2 (22), R114.2 (22), R115.2 (22), R116.2 (22), R118.2 (22), U9.3 (GND), U9.5 (GND), U9.21 (GND), X4.2 (GND); also elsewhere on the board
MISO2: U9.16 (PB4(MISO)); also elsewhere on the board
MOSI2: U9.15 (PB3(MOSI/OC2)); also elsewhere on the board
unnamed: Q28.1 (B), R95.1 (11)
unnamed: Q29.1 (G), R97.1 (11)
unnamed: Q28.3 (C), R94.2 (22), R97.2 (22)
unnamed: C33.1, D4.C (12), R94.1 (11)
unnamed: Q30.1 (G), R98.1 (11)
unnamed: Q31.1 (B), R101.1 (11)
unnamed: Q32.1 (G), R102.1 (11)
unnamed: Q31.3 (C), R100.2 (22), R102.2 (22)
unnamed: C34.1, D5.C (12), R100.1 (11)
unnamed: Q33.1 (G), R103.1 (11)
unnamed: Q34.1 (B), R106.1 (11)
unnamed: Q35.1 (G), R107.1 (11)
unnamed: Q34.3 (C), R105.2 (22), R107.2 (22)
unnamed: C35.1, D6.C (12), R105.1 (11)
unnamed: Q36.1 (G), R108.1 (11)
unnamed: R117.2 (22), U9.12 (PB0(ICP))
unnamed: JP4.1, U9.19 (ADC6)
unnamed: C36.2, U9.20 (AREF)
unnamed: U9.7 (PB6(XTAL1/TOSC1)), X4.3 (2)
unnamed: U9.8 (PB7(XTAL2/TOSC2)), X4.1
NEUTRAL_SENSE2: R96.2 (22), R109.2 (22), R110.2 (22), U9.10 (PD6(AIN0))
PWM2: R117.1 (11), R118.1 (11); also elsewhere on the board
RST2: C65.1, R93.1 (11), U9.29 (PC6(/RESET)); also elsewhere on the board
SCK2: U9.17 (PB5(SCK)); also elsewhere on the board
VDD: D4.A (21), D5.A (21), D6.A (21), Q29.2 (D), Q32.2 (D), Q35.2 (D); also elsewhere on the board

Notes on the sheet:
ESC2


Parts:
C1, C3, C4: 0.1uF (50V); 0402-M
C5, C67, C68, C69: 0.1uF; 0402-M
C7: 2.2uF; G-188-M
D1, D2, D3: 1N4148; SOD123-M
JP1: JUMPER-SMT_2_NO_NO-SILK; SMT-JUMPER_2_NO_NO-SILK
Q1, Q2, Q3: 500mA/300V; SOT23-3
Q4, Q5, Q6, Q7, Q8, Q9: IRLR8726; DPAK
R1, R3, R19, R24, R37, R38: 10k; RC0603N-M
R4, R20, R25: 2.2k; RC0603N-M
R5, R21, R26, R34, R35, R36: 4.7k; RC0603N-M
R6, R29, R30, R31, R32, R33: 47k; RC0603N-M
R17, R18, R22, R23, R27, R28: 100R; RC0603N-M
U8: MEGA8-AI; TQFP32-08
X1: 16MHz; 3-SMD

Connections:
+5V: C7.2 (22), C67.1, C69.2, R3.2 (22), U8.4 (VCC), U8.6 (VCC), U8.18 (AVCC); also elsewhere on the board
AHIN: R5.2 (22), U8.27 (PC4(ADC4/SDA))
ALIN: R1.1 (11), R18.2 (22), U8.30 (PD0(RXD))
AOUT: C1.2, Q4.3 (S), Q5.2 (D), R33.1 (11)
A_SENSE: R30.1 (11), R33.2 (22), R34.1 (11), U8.24 (PC1(ADC1))
BHIN: R21.2 (22), U8.31 (PD1(TXD))
BLIN: R19.1 (11), R23.2 (22), U8.28 (PC5(ADC5/SCL))
BOUT: C3.2, Q6.3 (S), Q7.2 (D), R32.1 (11)
B_SENSE: R29.1 (11), R32.2 (22), R35.1 (11), U8.23 (PC0(ADC0))
CHIN: R26.2 (22), U8.1 (PD3(INT1))
CLIN: R24.1 (11), R28.2 (22), U8.9 (PD5(T1))
COUT: C4.2, Q8.3 (S), Q9.2 (D), R31.1 (11)
C_SENSE: R6.1 (11), R31.2 (22), R36.1 (11), U8.22 (ADC7)
GND: C5.1, C7.1 (11), C67.2, C68.2, C69.1, JP1.2, Q1.2 (E), Q2.2 (E), Q3.2 (E), Q5.3 (S), Q7.3 (S), Q9.3 (S), R1.2 (22), R19.2 (22), R24.2 (22), R34.2 (22), R35.2 (22), R36.2 (22), R38.2 (22), U8.3 (GND), U8.5 (GND), U8.21 (GND), X1.2 (GND); also elsewhere on the board
MISO1: U8.16 (PB4(MISO)); also elsewhere on the board
MOSI1: U8.15 (PB3(MOSI/OC2)); also elsewhere on the board
unnamed: Q1.1 (B), R5.1 (11)
unnamed: Q4.1 (G), R17.1 (11)
unnamed: Q1.3 (C), R4.2 (22), R17.2 (22)
unnamed: Q2.1 (B), R21.1 (11)
unnamed: C1.1, D1.C (12), R4.1 (11)
unnamed: Q5.1 (G), R18.1 (11)
unnamed: Q6.1 (G), R22.1 (11)
unnamed: Q2.3 (C), R20.2 (22), R22.2 (22)
unnamed: C3.1, D2.C (12), R20.1 (11)
unnamed: Q7.1 (G), R23.1 (11)
unnamed: Q3.1 (B), R26.1 (11)
unnamed: Q8.1 (G), R27.1 (11)
unnamed: Q3.3 (C), R25.2 (22), R27.2 (22)
unnamed: C4.1, D3.C (12), R25.1 (11)
unnamed: Q9.1 (G), R28.1 (11)
unnamed: C5.2, U8.20 (AREF)
unnamed: U8.7 (PB6(XTAL1/TOSC1)), X1.3 (2)
unnamed: U8.8 (PB7(XTAL2/TOSC2)), X1.1
unnamed: JP1.1, U8.19 (ADC6)
unnamed: R37.2 (22), U8.12 (PB0(ICP))
NEUTRAL_SENSE: R6.2 (22), R29.2 (22), R30.2 (22), U8.10 (PD6(AIN0))
PWM: R37.1 (11), R38.1 (11); also elsewhere on the board
RST1: C68.1, R3.1 (11), U8.29 (PC6(/RESET)); also elsewhere on the board
SCK1: U8.17 (PB5(SCK)); also elsewhere on the board
VDD: D1.A (21), D2.A (21), D3.A (21), Q4.2 (D), Q6.2 (D), Q8.2 (D); also elsewhere on the board

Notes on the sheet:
ESC1


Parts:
C28, C29, C30: 0.1uF (50V); 0402-M
C31, C70, C71, C72: 0.1uF; 0402-M
C32: 2.2uF; G-188-M
D7, D8, D9: 1N4148; SOD123-M
JP3: JUMPER-SMT_2_NO_NO-SILK; SMT-JUMPER_2_NO_NO-SILK
Q19, Q22, Q25: 500mA/300V; SOT23-3
Q20, Q21, Q23, Q24, Q26, Q27: IRLR8726; DPAK
R65, R66, R72, R77, R90, R91: 10k; RC0603N-M
R67, R73, R78: 2.2k; RC0603N-M
R68, R74, R79, R87, R88, R89: 4.7k; RC0603N-M
R69, R82, R83, R84, R85, R86: 47k; RC0603N-M
R70, R71, R75, R76, R80, R81: 100R; RC0603N-M
U10: MEGA8-AI; TQFP32-08
X3: 16MHz; 3-SMD

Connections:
+5V: C32.2 (22), C70.1, C72.2, R66.2 (22), U10.4 (VCC), U10.6 (VCC), U10.18 (AVCC); also elsewhere on the board
AHIN3: R68.2 (22), U10.27 (PC4(ADC4/SDA))
ALIN3: R65.1 (11), R71.2 (22), U10.30 (PD0(RXD))
AOUT3: C28.2, Q20.3 (S), Q21.2 (D), R86.1 (11)
A_SENSE3: R83.1 (11), R86.2 (22), R87.1 (11), U10.24 (PC1(ADC1))
BHIN3: R74.2 (22), U10.31 (PD1(TXD))
BLIN3: R72.1 (11), R76.2 (22), U10.28 (PC5(ADC5/SCL))
BOUT3: C29.2, Q23.3 (S), Q24.2 (D), R85.1 (11)
B_SENSE3: R82.1 (11), R85.2 (22), R88.1 (11), U10.23 (PC0(ADC0))
CHIN3: R79.2 (22), U10.1 (PD3(INT1))
CLIN3: R77.1 (11), R81.2 (22), U10.9 (PD5(T1))
COUT3: C30.2, Q26.3 (S), Q27.2 (D), R84.1 (11)
C_SENSE3: R69.1 (11), R84.2 (22), R89.1 (11), U10.22 (ADC7)
GND: C31.1, C32.1 (11), C70.2, C71.2, C72.1, JP3.2, Q19.2 (E), Q21.3 (S), Q22.2 (E), Q24.3 (S), Q25.2 (E), Q27.3 (S), R65.2 (22), R72.2 (22), R77.2 (22), R87.2 (22), R88.2 (22), R89.2 (22), R91.2 (22), U10.3 (GND), U10.5 (GND), U10.21 (GND), X3.2 (GND); also elsewhere on the board
MISO3: U10.16 (PB4(MISO)); also elsewhere on the board
MOSI3: U10.15 (PB3(MOSI/OC2)); also elsewhere on the board
unnamed: Q19.1 (B), R68.1 (11)
unnamed: Q20.1 (G), R70.1 (11)
unnamed: Q19.3 (C), R67.2 (22), R70.2 (22)
unnamed: C28.1, D7.C (12), R67.1 (11)
unnamed: Q21.1 (G), R71.1 (11)
unnamed: Q22.1 (B), R74.1 (11)
unnamed: Q23.1 (G), R75.1 (11)
unnamed: Q22.3 (C), R73.2 (22), R75.2 (22)
unnamed: C29.1, D8.C (12), R73.1 (11)
unnamed: Q24.1 (G), R76.1 (11)
unnamed: Q25.1 (B), R79.1 (11)
unnamed: Q26.1 (G), R80.1 (11)
unnamed: Q25.3 (C), R78.2 (22), R80.2 (22)
unnamed: C30.1, D9.C (12), R78.1 (11)
unnamed: Q27.1 (G), R81.1 (11)
unnamed: R90.2 (22), U10.12 (PB0(ICP))
unnamed: JP3.1, U10.19 (ADC6)
unnamed: C31.2, U10.20 (AREF)
unnamed: U10.7 (PB6(XTAL1/TOSC1)), X3.3 (2)
unnamed: U10.8 (PB7(XTAL2/TOSC2)), X3.1
NEUTRAL_SENSE3: R69.2 (22), R82.2 (22), R83.2 (22), U10.10 (PD6(AIN0))
PWM3: R90.1 (11), R91.1 (11); also elsewhere on the board
RST3: C71.1, R66.1 (11), U10.29 (PC6(/RESET)); also elsewhere on the board
SCK3: U10.17 (PB5(SCK)); also elsewhere on the board
VDD: D7.A (21), D8.A (21), D9.A (21), Q20.2 (D), Q23.2 (D), Q26.2 (D); also elsewhere on the board

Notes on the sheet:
ESC3


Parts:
C39, C40, C41: 0.1uF (50V); 0402-M
C42, C73, C74, C75: 0.1uF; 0402-M
C43: 2.2uF; G-188-M
D10, D11, D12: 1N4148; SOD123-M
JP5: JUMPER-SMT_2_NO_NO-SILK; SMT-JUMPER_2_NO_NO-SILK
Q37, Q40, Q43: 500mA/300V; SOT23-3
Q38, Q39, Q41, Q42, Q44, Q45: IRLR8726; DPAK
R119, R120, R126, R131, R144, R145: 10k; RC0603N-M
R121, R127, R132: 2.2k; RC0603N-M
R122, R128, R133, R141, R142, R143: 4.7k; RC0603N-M
R123, R136, R137, R138, R139, R140: 47k; RC0603N-M
R124, R125, R129, R130, R134, R135: 100R; RC0603N-M
U11: MEGA8-AI; TQFP32-08
X5: 16MHz; 3-SMD

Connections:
+5V: C43.2 (22), C73.1, C75.2, R120.2 (22), U11.4 (VCC), U11.6 (VCC), U11.18 (AVCC); also elsewhere on the board
AHIN4: R122.2 (22), U11.27 (PC4(ADC4/SDA))
ALIN4: R119.1 (11), R125.2 (22), U11.30 (PD0(RXD))
AOUT4: C39.2, Q38.3 (S), Q39.2 (D), R140.1 (11)
A_SENSE4: R137.1 (11), R140.2 (22), R141.1 (11), U11.24 (PC1(ADC1))
BHIN4: R128.2 (22), U11.31 (PD1(TXD))
BLIN4: R126.1 (11), R130.2 (22), U11.28 (PC5(ADC5/SCL))
BOUT4: C40.2, Q41.3 (S), Q42.2 (D), R139.1 (11)
B_SENSE4: R136.1 (11), R139.2 (22), R142.1 (11), U11.23 (PC0(ADC0))
CHIN4: R133.2 (22), U11.1 (PD3(INT1))
CLIN4: R131.1 (11), R135.2 (22), U11.9 (PD5(T1))
COUT4: C41.2, Q44.3 (S), Q45.2 (D), R138.1 (11)
C_SENSE4: R123.1 (11), R138.2 (22), R143.1 (11), U11.22 (ADC7)
GND: C42.1, C43.1 (11), C73.2, C74.2, C75.1, JP5.2, Q37.2 (E), Q39.3 (S), Q40.2 (E), Q42.3 (S), Q43.2 (E), Q45.3 (S), R119.2 (22), R126.2 (22), R131.2 (22), R141.2 (22), R142.2 (22), R143.2 (22), R145.2 (22), U11.3 (GND), U11.5 (GND), U11.21 (GND), X5.2 (GND); also elsewhere on the board
MISO4: U11.16 (PB4(MISO)); also elsewhere on the board
MOSI4: U11.15 (PB3(MOSI/OC2)); also elsewhere on the board
unnamed: Q37.1 (B), R122.1 (11)
unnamed: Q38.1 (G), R124.1 (11)
unnamed: Q37.3 (C), R121.2 (22), R124.2 (22)
unnamed: C39.1, D10.C (12), R121.1 (11)
unnamed: Q39.1 (G), R125.1 (11)
unnamed: Q40.1 (B), R128.1 (11)
unnamed: Q41.1 (G), R129.1 (11)
unnamed: Q40.3 (C), R127.2 (22), R129.2 (22)
unnamed: C40.1, D11.C (12), R127.1 (11)
unnamed: Q42.1 (G), R130.1 (11)
unnamed: Q43.1 (B), R133.1 (11)
unnamed: Q44.1 (G), R134.1 (11)
unnamed: Q43.3 (C), R132.2 (22), R134.2 (22)
unnamed: C41.1, D12.C (12), R132.1 (11)
unnamed: Q45.1 (G), R135.1 (11)
unnamed: R144.2 (22), U11.12 (PB0(ICP))
unnamed: JP5.1, U11.19 (ADC6)
unnamed: C42.2, U11.20 (AREF)
unnamed: U11.7 (PB6(XTAL1/TOSC1)), X5.3 (2)
unnamed: U11.8 (PB7(XTAL2/TOSC2)), X5.1
NEUTRAL_SENSE4: R123.2 (22), R136.2 (22), R137.2 (22), U11.10 (PD6(AIN0))
PWM4: R144.1 (11), R145.1 (11); also elsewhere on the board
RST4: C74.1, R120.1 (11), U11.29 (PC6(/RESET)); also elsewhere on the board
SCK4: U11.17 (PB5(SCK)); also elsewhere on the board
VDD: D10.A (21), D11.A (21), D12.A (21), Q38.2 (D), Q41.2 (D), Q44.2 (D); also elsewhere on the board

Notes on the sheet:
ESC4


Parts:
C2, C17: 22uF; 1210_CAPACITOR
C14, C52: 10nF; 0603_CAPACITOR
C18: 1nF; C0402
C26, C54: 0.1uF; 0402-M
C44, C55: 43pF; C0603
C47, C56, C63, C64: 22uF; C0805
C53: 2.2nF; 0402_CAPACITOR
D13, D14: SSB44-E3/52T; DIODE_DO214AA_MBRS-M
F1, F2: 0ZRB0400FF1A
L1, L2: 10uH; PA431.XXX
R2: 3.24k; R0603
R7: 28.7k; R0402
R8: 1.96k; R0603
R9: 39.2k; R0402
R10, R16: 10.2k; R0402
R11, R13, R15: 100k; RC0603N-M
R14: 1k; RC0603N-M
R39: 2.2k; RC0603N-M
U1, U12: TPS54331DRD8-M; D8-M
U14: SN74LVC1G373DCKRDCK6-M; DCK6-M

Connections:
+3V3: C56.1, C63.1, L1.P$2 (2), R16.2; also elsewhere on the board
+5V: C47.1, C64.1, L2.P$2 (2), R10.2; also elsewhere on the board
EN: R11.2 (22), R15.1 (11), U1.3 (EN), U12.3 (EN), U14.4 (Q)
GND: C2.2, C14.1, C17.2, C18.2, C44.2, C47.2, C52.1, C53.1, C55.2, C56.2, C63.2, C64.2, D13.2 (21), D14.2 (21), R2.1, R8.1, R14.2 (22), U1.7 (GND), U1.EP (GND), U12.7 (GND), U12.EP (GND), U14.2 (GND); also elsewhere on the board
unnamed: C55.1, R7.2, U12.6 (COMP)
unnamed: C53.2, R7.1
unnamed: C52.2, U12.4 (SS)
unnamed: C54.1, U12.1 (BOOT)
unnamed: C44.1, R9.2, U1.6 (COMP)
unnamed: C18.1, R9.1
unnamed: C14.2, U1.4 (SS)
unnamed: C26.1, U1.1 (BOOT)
unnamed: C26.2, D14.1 (12), L2.P$1 (1), U1.8 (PH)
unnamed: C54.2, D13.1 (12), L1.P$1 (1), U12.8 (PH)
unnamed: R8.2, R10.1, U1.5 (VSENSE)
unnamed: R2.2, R16.1, U12.5 (VSENSE)
PWR_EN: R13.2 (22), U14.3 (D), U14.6 (!OE); also elsewhere on the board
V2FUSED: C17.1, F2.2, U1.2 (VIN)
VDD: F1.1, F2.1, R39.1 (11); also elsewhere on the board
VFUSED: C2.1, F1.2, U12.2 (VIN)
V_LATCH: R11.1 (11), R13.1 (11), R14.1 (11), R15.2 (22), R39.2 (22), U14.1 (LE), U14.5 (VCC)

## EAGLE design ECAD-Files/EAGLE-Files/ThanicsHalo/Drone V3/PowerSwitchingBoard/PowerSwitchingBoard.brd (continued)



Board: 4 copper layers, 80.0 x 88.0 mm, 282 parts (79 on the bottom side), 219 nets.

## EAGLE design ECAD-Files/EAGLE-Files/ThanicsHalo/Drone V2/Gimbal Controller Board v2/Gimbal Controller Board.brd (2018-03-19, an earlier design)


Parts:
C2, C3: 4.7uF; 0603-M
C6, C8, C10, C12: 0.1uF; 0402-M
C7, C9, C11: 10uF; 0805_CAPACITOR
D3: GREEN; LED-0603
J1, J2: JST_SH_3POS
J3: GIMBAL_POWER_CONNECTOR; XH_CONNECTOR
J4, J5: SERVO_CONNECTOR
J6: JST_SH_2POS
J7: JST_SH_4POS
J8: USB_MICRO_B_SMT
R1, R2, R3, R5, R6, R18: 10k; RC0805N
R4: 1k; RC0603N-M
R17: 68k; RC0402N-M
TP1, TP2, TP3, TP4: TPB2,54; B2,54
U2, U5, U6: DRV8839DSSR; DSS12_P9X2
U4: CP2102-GMRQFN28_5X5-M; QFN28_5X5-M
U7: STM32F303; LQFP48
U8: ATSHA204A; UDFN8_3X2
U9: CAT24C256; UDFN8_3X2
X1: CSTCE8M00G55Z; 3-SMD

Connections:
+3V3: C2.2, C3.2, C8.2, C10.2, C12.2, J7.2, R1.2 (22), R3.1 (11), R5.1 (11), TP4.TP, U2.12 (VCC), U5.12 (VCC), U6.12 (VCC), U7.1 (VBAT), U7.9 (VDDA), U7.24 (VDD), U7.36 (VDD), U7.48 (VDD), U8.8 (VCC), U9.8 (VCC); also elsewhere on the board
+5V: J4.2 (5V), J5.2 (5V); also elsewhere on the board
+10V: C7.2, C9.2, C11.2, U2.1 (VM_2), U2.2 (VM), U5.1 (VM_2), U5.2 (VM), U6.1 (VM_2), U6.2 (VM); also elsewhere on the board
BTN: TP1.TP, U7.2 (PC13)
EN_MOTOR: U2.7 (EN2), U2.9 (EN1), U2.11 (NSLEEP), U5.7 (EN2), U5.9 (EN1), U5.11 (NSLEEP), U6.7 (EN2), U6.9 (EN1), U6.11 (NSLEEP), U7.21 (PB10)
GND: C2.1, C3.1, C6.1, C7.1, C8.1, C9.1, C10.1, C11.1, C12.1, J3.2 (GND), J4.3 (GND), J5.3 (GND), J7.1, J8.5 (GND), J8.6 (GND), J8.7 (GND), J8.P$1 (GND), J8.P$2 (GND), J8.P$3 (GND), J8.P$4 (GND), R2.2 (22), R4.2 (22), R18.2 (22), TP2.TP, U2.5 (GND_2), U2.6 (GND), U2.13 (EPAD), U4.3 (GND), U4.29 (EPAD), U5.5 (GND_2), U5.6 (GND), U5.13 (EPAD), U6.5 (GND_2), U6.6 (GND), U6.13 (EPAD), U7.8 (VSSA), U7.23 (VSS), U7.35 (VSS), U7.47 (VSS), U8.4 (GND), U9.1 (A0), U9.2 (A1), U9.3 (A2), U9.4 (VSS), U9.7 (WP), U9.9 (VSS), X1.2 (GND); also elsewhere on the board
I2C1_SCL: J7.4, U7.38 (PA15)
I2C1_SDA: J7.3, U7.37 (PA14)
I2C2_SCL: R3.2 (22), U7.42 (PB6), U8.6 (SCL), U9.6 (SCL)
I2C2_SDA: R5.2 (22), U7.43 (PB7), U8.5 (SDA), U9.5 (SDA)
LED: D3.A, U7.25 (PB12)
unnamed: U7.5 (OSC_IN), X1.3 (2)
unnamed: R1.1 (11), U7.7 (NRST)
unnamed: D3.C, R4.1 (11)
unnamed: R2.1 (11), TP3.TP, U7.44 (BOOT0)
unnamed: J8.2 (D-), U4.5 (D-)
unnamed: J8.3 (D+), U4.4 (D+)
unnamed: R6.1 (11), U4.9 (!RST)
unnamed: C6.2, U4.6 (VDD)
unnamed: U7.6 (OSC_OUT), X1.1
P$1: J8.1 (VCC), R6.2 (22), U4.7 (REGIN), U4.8 (VBUS)
PITCH1: J2.3, U6.3 (OUT1)
PITCH2: J2.2, U6.4 (OUT2)
PITCH3: J2.1, U5.3 (OUT1)
RC_PITCH: U7.41 (PB5)
ROLL1: J1.3, U5.4 (OUT2)
ROLL2: J1.2, U2.3 (OUT1)
ROLL3: J1.1, U2.4 (OUT2)
SERVO1: J4.1 (SIG)
SERVO2: J5.1 (SIG)
TIM1_CH1N: U5.8 (IN2), U7.26 (PB13)
TIM1_CH2N: U2.10 (IN1), U7.27 (PB14)
TIM1_CH3N: U2.8 (IN2), U7.28 (PB15)
TIM3_CH2: U5.10 (IN1), U7.14 (PA4)
TIM3_CH3: U6.10 (IN1), U7.18 (PB0)
TIM3_CH4: U6.8 (IN2), U7.19 (PB1)
USART1_RX: J6.1, U4.26 (TXD), U7.31 (PA10)
USART1_TX: J6.2, U4.25 (RXD), U7.30 (PA9)
VCC_MEASURE: R17.2 (22), R18.1 (11), U7.10 (PA0)
V_BATT: J3.1 (15V), R17.1 (11); also elsewhere on the board


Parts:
C1, C13, C18, C19: 10uF; 0805_CAPACITOR
C14, C15, C16: 0.1uF; 0402-M
C17: 1uF; YAG_CC0805
C20, C21: 22uF; G-21
C22, C23, C24: 2.2nF; 0402_CAPACITOR
C25: 100uF; 1210_CAPACITOR
L1, L2, L3: 4.7uH; 1008
R7: 45.3k; STA_RMCF0402-M
R8, R13: 73.2k; RC0402N-M
R9: 158k; RC0402N-M
R10, R11, R12: 10k; RC0805N
R14, R15, R16: 20k; RC0402N-M
U1: TPS65261RHBR; RHB32_3P45X3P45

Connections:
+3V3: C19.2, L2.P$2 (2), R7.1 (11), R10.1 (11); also elsewhere on the board
+5V: C20.2 (22), C21.2 (22), L3.P$2 (2), R8.2 (22), R11.1 (11); also elsewhere on the board
+10V: C25.2, L1.P$1 (1), R9.1 (11), R12.1 (11); also elsewhere on the board
GND: C1.1, C13.1, C17.1 (11), C18.1, C19.1, C20.1 (11), C21.1 (11), C22.1, C23.2, C24.2, C25.1, R10.2 (22), R11.2 (22), R12.2 (22), R13.1 (11), U1.4 (MODE), U1.11 (PGND2), U1.14 (PGND3), U1.21 (AGND), U1.27 (PGND1), U1.33 (EPAD); also elsewhere on the board
unnamed: C16.2, U1.16 (BST3)
unnamed: R8.1 (11), U1.19 (FB3)
unnamed: C14.1, U1.9 (BST2)
unnamed: R14.2 (22), U1.18 (COMP3)
unnamed: R9.2 (22), U1.6 (FB2)
unnamed: R13.2 (22), U1.20 (ROSC)
unnamed: C15.1, L2.P$1 (1), U1.26 (LX1)
unnamed: C15.2, U1.25 (BST1)
unnamed: R7.2 (22), U1.22 (FB1)
unnamed: C24.1, R14.1 (11)
unnamed: C16.1, L3.P$1 (1), U1.15 (LX3)
unnamed: C14.2, L1.P$2 (2), U1.10 (LX2)
unnamed: C17.2 (22), U1.5 (V7V)
unnamed: R16.1 (11), U1.7 (COMP2)
unnamed: C22.2, R16.2 (22)
unnamed: R15.2 (22), U1.23 (COMP1)
unnamed: C23.1, R15.1 (11)
V_BATT: C1.2, C13.2, C18.2, U1.12 (PVIN2), U1.13 (PVIN3), U1.28 (PVIN1), U1.29 (VIN); also elsewhere on the board



Board: 2 copper layers, 38.8 x 28.2 mm, 66 parts (46 on the bottom side), 54 nets.

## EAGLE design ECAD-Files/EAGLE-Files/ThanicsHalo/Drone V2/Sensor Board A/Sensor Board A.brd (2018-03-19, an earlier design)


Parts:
C1: 0.1uF; 0805
D1, D2, D3, D4, D5, D6: LED0603; LED-0603
J1, J2, J3, J4, J5, J6, J7, J8: HC-SR04; HC-SR04_FOOTPRINT
J9: JST_SH_3POS
JP1: PINHD-1X4; 1X04
R1, R2, R3, R4, R5, R6: 1k; RC0603N-M
U2: TCA6424ARGJRRGJ32-M; RGJ32-M

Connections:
+5V: C1.2, J1.VCC (5V), J2.VCC (5V), J3.VCC (5V), J4.VCC (5V), J5.VCC (5V), J6.VCC (5V), J7.VCC (5V), J8.VCC (5V), JP1.3, U2.27 (VCCP), U2.31 (VCCI)
ECHO1: J1.ECHO, U2.15 (P16)
ECHO2: J2.ECHO, U2.13 (P14)
ECHO3: J3.ECHO, U2.11 (P12)
ECHO4: J4.ECHO, U2.9 (P10)
ECHO5: J5.ECHO, U2.7 (P06)
ECHO6: J6.ECHO, U2.5 (P04)
ECHO7: J7.ECHO, U2.3 (P02)
ECHO8: J8.ECHO, U2.1 (P00)
GND: C1.1, J1.GND, J2.GND, J3.GND, J4.GND, J5.GND, J6.GND, J7.GND, J8.GND, JP1.4, R1.2 (22), R2.2 (22), R3.2 (22), R4.2 (22), R5.2 (22), R6.2 (22), U2.25 (GND), U2.26 (ADDR)
INT: J9.3, U2.32 (!INT)
unnamed: JP1.1, JP1.2
unnamed: D1.A, U2.17 (P20)
unnamed: D2.A, U2.18 (P21)
unnamed: D3.A, U2.19 (P22)
unnamed: D4.A, U2.20 (P23)
unnamed: D5.A, U2.21 (P24)
unnamed: D6.A, U2.22 (P25)
unnamed: D6.C, R6.1 (11)
unnamed: D5.C, R5.1 (11)
unnamed: D4.C, R4.1 (11)
unnamed: D3.C, R3.1 (11)
unnamed: D2.C, R2.1 (11)
unnamed: D1.C, R1.1 (11)
SCL: J9.2, U2.29 (SCL)
SDA: J9.1, U2.30 (SDA)
TRIG1: J1.TRIG, U2.16 (P17)
TRIG2: J2.TRIG, U2.14 (P15)
TRIG3: J3.TRIG, U2.12 (P13)
TRIG4: J4.TRIG, U2.10 (P11)
TRIG5: J5.TRIG, U2.8 (P07)
TRIG6: J6.TRIG, U2.6 (P05)
TRIG7: J7.TRIG, U2.4 (P03)
TRIG8: J8.TRIG, U2.2 (P01)



Board: 2 copper layers, 27.6 x 22.6 mm, 24 parts (6 on the bottom side), 34 nets.

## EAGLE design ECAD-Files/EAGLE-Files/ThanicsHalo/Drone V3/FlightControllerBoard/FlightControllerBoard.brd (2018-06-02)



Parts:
C1, C2, C3, C7, C8, C9, C11, C12, C14, C15, C16, C17, C25, C26, C27, C28, C29, C30, C31, C32, C33, C34, C35, C39, C40, C65, C66: 0.1uF; 0402-M
C4: 10nF; 0603_CAPACITOR
C5, C18: 4.7uF; 0603-M
C6: 1uF; YAG_CC0805
C10, C21: 2.2uF; G-188-M
C13, C20: 0.1uF; 0805
C24, C41, C43: 22uF; G-21
C42, C62, C67: 10uF; G-21
D1, D2, D4: GREEN; LED-0603
J1, J2, J3, J9, J10, J11, J15, J16, J17, J18, J19, J20, J21, J22: JST_SH_4POS
J4, J12: UE27AE54100; USBA_RECEPT_VERT
J5: U.FL
J7: 62674-301121ALF; CON30_1X30_DUT_58XF
J8: MICROSD
J13, J14: 0526101572_15ZIF_CONNECTOR; 15POS_FFC_CONNECTOR
JP1: PINHD-1X1; 1X01
L1: 27 nH; 0402_INDUCTOR
L2, L3: FB; IND_BLM18_0603-M
L4: 1k@100MHz; IND_BLM18_0603-M
R1: 12k; RC0402N-M
R2, R10, R14, R29, R32: 10k; RC0603N-M
R3, R5, R6, R7, R8, R9: 20R; RC0603N-M
R4: 12.4k; YAG_R0402-M
R12: 10R; STA_RNCP0805-M
R15, R16, R17, R18, R19, R28, R31: 1k; RC0603N-M
R20, R21, R22, R23, R24, R25, R26, R27: 49R9; RC0402N-M
T1, T2: ALT4532M; ALT4532
U1: ICM-20948; QFN40P300X300X105-25N
U2: LAN9512-JZXQFN64_9X9MC-M; QFN64_9X9MC-M
U3: MPL115A2; LGA8-M
U4: NEO-M8
U5: AZ1117EH-1.8; SOT-223
U6: COMPUTE_MODULE; SO-DIMM
U7: PDDL2450; PDDL2450_SOCKET
U8: 74HC4053; TSSOP16
U9: FXMAR2102; 8-UMLP
U10: STM32F446; LQFP64
U11: ESP12ESMD; ESP12E-SMD

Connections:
1.8V: C2.1, C9.1, C11.2, C66.2, C67.2 (22), U1.8 (VDDIO), U1.9 (AD0/SDO), U1.13 (VDD), U1.22 (CS), U5.2 (OUT), U5.4 (OUT), U6.183 (1V8), U6.184 (1V8), U6.185 (1V8), U6.186 (1V8), U9.8 (VCCB)
3.3V_A: C8.2, C14.2, C15.2, C16.2, C17.2, C25.2, L3.1, R20.1 (11), R21.1 (11), R22.1 (11), R23.1 (11), R28.2 (22), T1.3, T2.3, U2.5 (VDD33A_2), U2.10 (VDD33A_3), U2.49 (VDD33A_4), U2.51 (VDD33A_5), U2.54 (VDD33A_6), U2.57 (VDD33A_7), U2.64 (VDD33A)
+3V3: C7.2, C10.2 (22), C13.2, C20.2, C21.2 (22), C26.2, C27.2, C28.2, C29.2, C30.2, C35.2, C39.2, C42.1 (11), J1.1, J2.1, J3.3, J7.3 (33), J7.4 (44), J7.5 (55), J7.6 (66), J8.4 (VDD), J9.1, J10.1, J11.1, J13.15, J14.15, J15.1, J16.1, J17.1, J18.1, J19.1, J20.1, J21.1, J22.1, L3.2, R2.1 (11), R15.1 (11), R16.1 (11), R17.1 (11), R18.1 (11), R19.2 (22), R29.2 (22), U2.11 (VBUS_DET), U2.12 (NRESET), U2.19 (VDD33IO_2), U2.27 (VDD33IO_3), U2.33 (VDD33IO_4), U2.39 (VDD33IO_5), U2.40 (TEST3), U2.46 (VDD33IO), U3.1 (VDD), U3.4 (VDDIO), U4.22 (22_V_BCKP), U4.23 (23_VCC), U6.4 (SDX_VDD), U6.6 (SDX_VDD), U6.39 (GPIO0-27_VDD), U6.40 (GPIO0-27_VDD), U6.41 (GPIO28-45_VDD), U6.42 (GPIO28-45_VDD), U6.191 (3V3), U6.192 (3V3), U6.193 (3V3), U6.194 (3V3), U6.197 (VBAT), U6.198 (VBAT), U6.199 (VBAT), U6.200 (VBAT), U7.61 (VCC), U7.62 (VCC), U8.16 (VCC), U9.1 (VCCA), U9.5 (OE), U10.1 (VBAT), U10.13 (VDDA), U10.19 (VDD), U10.32 (VDD), U10.48 (VDD), U10.64 (VDD), U11.VCC
+5V: C24.2 (22), C41.1 (11), C43.2 (22), C62.2 (22), C65.2, J4.1 (VCC), J7.1 (11), J7.2 (22), J12.1 (VCC), U5.3 (IN), U7.63 (VRF), U7.64 (VRF)
C0_C_N: J13.8, U6.144 (CAM0_CN)
C0_C_P: J13.9, U6.142 (CAM0_CP)
C0_D0_N: J13.2, U6.138 (CAM0_DN0)
C0_D0_P: J13.3, U6.136 (CAM0_DP0)
C0_D1_N: J13.5, U6.150 (CAM0_DN1)
C0_D1_P: J13.6, U6.148 (CAM0_DP1)
C0_IO0: J13.11, U6.36 (GPIO31)
C0_IO1: J13.12, U6.34 (GPIO30)
C1_C_N: J14.8, U6.149 (CAM1_CN)
C1_C_P: J14.9, U6.147 (CAM1_CP)
C1_D0_N: J14.2, U6.161 (CAM1_DN0)
C1_D0_P: J14.3, U6.159 (CAM1_DP0)
C1_D1_N: J14.5, U6.155 (CAM1_DN1)
C1_D1_P: J14.6, U6.153 (CAM1_DP1)
C1_IO0: J14.11, U6.78 (GPIO43)
C1_IO1: J14.12, U6.76 (GPIO42)
EMMC_DISABLE_N: U6.2 (EMMC_DISABLE_N)
ETH_BIAS: C1.2, L4.2, U7.13 (ETH_BIAS)
GEAR: JP1.1, U6.65 (GPIO19)
GND: C1.1, C2.2, C3.1, C4.1, C5.1, C6.1 (11), C7.1, C8.1, C9.2, C10.1 (11), C11.1, C12.1, C13.1, C14.1, C15.1, C16.1, C17.1, C18.1, C20.1, C21.1 (11), C24.1 (11), C25.1, C26.1, C27.1, C28.1, C29.1, C30.1, C31.1, C32.1, C33.1, C34.1, C35.1, C39.1, C40.1, C41.2 (22), C42.2 (22), C43.1 (11), C62.1 (11), C65.1, C66.1, C67.1 (11), D1.C, J1.4, J2.4, J3.4, J4.4 (GND), J4.P$5 (GND), J4.P$6 (GND), J5.P$1 (GND), J5.P$2 (GND), J7.7 (77), J7.8 (88), J7.27 (2727), J7.28 (2828), J7.29 (2929), J7.30 (3030), J8.6 (VSS), J8.9 (VSS), J8.10 (VSS), J8.11 (VSS), J8.12 (VSS), J8.13 (VSS), J9.4, J10.4, J11.4, J12.4 (GND), J12.P$5 (GND), J12.P$6 (GND), J13.1, J13.4, J13.7, J13.10, J14.1, J14.4, J14.7, J14.10, J15.4, J16.4, J17.4, J18.4, J19.4, J20.4, J21.4, J22.4, R1.2 (22), R4.1 (11), R10.2 (22), R14.1 (11), R31.2 (22), R32.2 (22), U1.11 (FSYNC), U1.18 (GND), U1.20 (GND), U2.34 (TEST2), U2.44 (CLK24_EN), U2.65 (EPAD), U3.3 (GND), U4.7 (7_VDD_USB), U4.10 (10_GND), U4.12 (12_GND), U4.13 (13_GND), U4.24 (24_GND), U5.1 (GND), U6.1 (GND), U6.7 (GND), U6.8 (GND), U6.13 (GND), U6.14 (GND), U6.19 (GND), U6.20 (GND), U6.25 (GND), U6.26 (GND), U6.31 (GND), U6.32 (GND), U6.37 (GND), U6.38 (GND), U6.43 (GND), U6.44 (GND), U6.49 (GND), U6.50 (GND), U6.55 (GND), U6.56 (GND), U6.61 (GND), U6.62 (GND), U6.67 (GND), U6.68 (GND), U6.73 (GND), U6.74 (GND), U6.79 (GND), U6.80 (GND), U6.85 (GND), U6.86 (GND), U6.91 (GND), U6.92 (GND), U6.97 (GND), U6.98 (GND), U6.103 (GND), U6.104 (GND), U6.109 (GND), U6.110 (GND), U6.115 (GND), U6.116 (GND), U6.121 (GND), U6.122 (GND), U6.127 (GND), U6.133 (GND), U6.134 (GND), U6.139 (GND), U6.140 (GND), U6.145 (GND), U6.146 (GND), U6.151 (GND), U6.152 (GND), U6.157 (GND), U6.163 (GND), U6.164 (GND), U6.169 (GND), U6.170 (GND), U6.181 (GND), U6.182 (GND), U6.187 (GND), U6.188 (GND), U6.195 (GND), U6.196 (GND), U6.G1, U6.G2, U7.1 (GND), U7.17 (GND), U7.25 (GND), U7.26 (GND), U7.39 (GND), U7.40 (GND), U7.65, U7.66, U7.67, U7.68, U7.69, U7.70, U7.71, U7.72, U7.73, U7.74, U7.75, U7.76, U7.77, U7.78, U7.79, U7.80, U8.6 (!E), U8.7 (GND), U8.8 (GND), U9.4 (GND), U10.12 (VSSA), U10.18 (VSS), U10.31 (VSS), U10.47 (VSS), U10.63 (VSS), U11.GND
GND1: D2.C, U7.60 (LINK_LED_LAN)
GPCLK1: R10.1 (11), U2.61 (XI), U6.82 (GPIO44)
GPIO12: U6.45 (GPIO12)
GPIO13: U6.47 (GPIO13)
GPIO16: U6.57 (GPIO16)
GPIO17: U6.59 (GPIO17)
GPIO37: U6.60 (GPIO37)
GPIO38: U6.64 (GPIO38)
GPIO39: U6.66 (GPIO39)
I2C_MPU_SCL: U9.3 (A1), U10.61 (PB8)
I2C_MPU_SDA: U9.2 (A0), U10.62 (PB9)
I2C_SCL: J1.3, J2.3, J7.20 (2020), J9.3, J10.3, J11.3, J15.3, J16.3, J17.3, J18.3, J19.3, J20.3, J21.3, J22.3, U3.8 (SCL), U4.19 (19_SCL/SPI_CLK), U6.11 (GPIO3)
I2C_SCL_1V8: U1.23 (SCL/SCLK), U9.6 (B1)
I2C_SDA: J1.2, J2.2, J7.19 (1919), J9.2, J10.2, J11.2, J15.2, J16.2, J17.2, J18.2, J19.2, J20.2, J21.2, J22.2, U3.7 (SDL), U4.18 (18_SDA/SPI_CS_N), U6.9 (GPIO2)
I2C_SDA_1V8: U1.24 (SDA/SDI), U9.7 (B0)
ID_SD: U6.15 (GPIO4), U11.CH_PD
MISO: J7.13 (1313), U6.52 (GPIO34)
MOSI: J7.12 (1212), U6.48 (GPIO33)
unnamed: J5.P$3 (SIGNAL), L1.P$1 (1), U4.11 (11_RF_IN)
unnamed: C34.2, U1.10 (REGOUT)
unnamed: R29.1 (11), U2.41 (AUTOMDIX_EN)
unnamed: D1.A, R19.1 (11)
unnamed: R1.1 (11), U2.63 (USBRBIAS)
unnamed: C40.2, U3.2 (CAP)
unnamed: R3.1 (11), U11.CS0
unnamed: R5.1 (11), U11.MISO
unnamed: R6.1 (11), U11.GPIO9 (*GPIO9)
unnamed: R7.1 (11), U11.GPIO10 (*GPIO10)
unnamed: C5.2, U10.30 (VCAP_1)
unnamed: D2.A, R28.1 (11)
unnamed: R12.1 (11), U4.9 (9_VCC_RF)
unnamed: R8.1 (11), U11.MOSI
unnamed: R9.1 (11), U11.SCLK
unnamed: R14.2 (22), U10.60 (BOOT0)
unnamed: C31.2, L2.1, U2.48 (VDD18ETHPLL)
unnamed: C6.2 (22), L2.2, U2.62 (VDD18USBPLL)
unnamed: R4.2 (22), U2.50 (EXRES)
unnamed: C18.2, C32.2, C33.2, U2.15 (VDD18CORE_2), U2.38 (VDD18CORE)
unnamed: C3.2, C12.2, L4.1, R24.1 (11), R25.1 (11), R26.1 (11), R27.1 (11), T1.6, T2.6
unnamed: R2.2 (22), U7.15 (CONFIG)
unnamed: D4.A, U7.11 (CPU_STAT_LED)
unnamed: C4.2, L1.P$2 (2), R12.2 (22)
unnamed: D4.C, R31.1 (11)
unnamed: R32.1 (11), U6.168 (USB_OTGID)
NRST: U6.63 (GPIO18), U8.4 (3Z)
NRST1: U8.5 (3Y0), U10.7 (NRST)
NRST2: J7.17 (1717), U8.3 (3Y1)
PWM: J7.23 (2323), U10.24 (PC4)
PWM2: J7.24 (2424), U10.25 (PC5)
PWM3: J7.25 (2525), U10.26 (PB0)
PWM4: J7.26 (2626), U10.27 (PB1)
PWR_EN: J7.18 (1818), U6.58 (GPIO36)
RST: J7.11 (1111), U6.46 (GPIO32)
RX_LAN_N: R26.2 (22), T1.1, U7.57 (RX_N_LAN)
RX_LAN_P: R25.2 (22), T1.2, U7.58 (RX_P_LAN)
RX_N: R23.2 (22), T1.5, U2.53 (RXN)
RX_P: R22.2 (22), T1.4, U2.52 (RXP)
SCK: J7.14 (1414), U6.54 (GPIO35)
SCL0: J13.13, R16.2 (22), U6.30 (GPIO29)
SCL1: J14.13, R18.2 (22), U6.5 (GPIO1)
SDA0: J13.14, R15.2 (22), U6.28 (GPIO28)
SDA1: J14.14, R17.2 (22), U6.3 (GPIO0)
SDX_CLK: J8.5 (CLK), U6.10 (SDX_CLK)
SDX_CMD: J8.3 (CMD), U6.12 (SDX_CMD)
SDX_D0: J8.7 (DAT0), U6.16 (SDX_D0)
SDX_D1: J8.8 (DAT1), U6.18 (SDX_D1)
SDX_D2: J8.1 (DAT2), U6.22 (SDX_D2)
SDX_D3: J8.2 (CD/DAT3), U6.24 (SDX_D3)
SD_CLK: R9.2 (22), U6.75 (GPIO22)
SD_CMD: R3.2 (22), U6.77 (GPIO23)
SD_D0: R5.2 (22), U6.81 (GPIO24)
SD_D1: R8.2 (22), U6.83 (GPIO25)
SD_D2: R6.2 (22), U6.87 (GPIO26)
SD_D3: R7.2 (22), U6.89 (GPIO27)
SEL0: J7.9 (99), U6.21 (GPIO6)
SEL1: J7.10 (1010), U6.23 (GPIO7)
SEL2: U6.17 (GPIO5), U8.9 (S3), U8.10 (S2), U8.11 (S1)
SPI_CS0: U6.27 (GPIO8), U10.20 (PA4)
SPI_MISO: U6.29 (GPIO9), U10.22 (PA6)
SPI_MOSI: U6.33 (GPIO10), U10.23 (PA7)
SPI_SCLK: U6.35 (GPIO11), U10.21 (PA5)
SWCLK: U6.69 (GPIO20), U8.15 (2Z)
SWCLK1: U8.2 (2Y0), U10.49 (PA14)
SWCLK2: J7.16 (1616), U8.1 (2Y1)
SWDIO: U6.71 (GPIO21), U8.14 (1Z)
SWDIO1: U8.12 (1Y0), U10.46 (PA13)
SWDIO2: J7.15 (1515), U8.13 (1Y1)
TX_LAN_N: R27.2 (22), T2.2, U7.56 (TX_N_LAN)
TX_LAN_P: R24.2 (22), T2.1, U7.55 (TX_P_LAN)
TX_N: R20.2 (22), T2.4, U2.56 (TXN)
TX_P: R21.2 (22), T2.5, U2.55 (TXP)
UART2_RX: J7.21 (2121), U6.72 (GPIO41)
UART2_TX: J7.22 (2222), U6.70 (GPIO40)
USART1_RX: J3.1, U6.53 (GPIO15), U10.59 (PB7)
USART1_TX: J3.2, U6.51 (GPIO14)
USB_D2_N: J12.2 (D-), U2.1 (USBDM2)
USB_D2_P: J12.3 (D+), U2.2 (USBDP2)
USB_D3_N: J4.2 (D-), U2.3 (USBDM3)
USB_D3_P: J4.3 (D+), U2.4 (USBDP3)
USB_D_N: U2.58 (USBDM0), U6.167 (USB_DM)
USB_D_P: U2.59 (USBDP0), U6.165 (USB_DP)

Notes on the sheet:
To Telemetry Transeiver
Communications
RPi Compute Module
Sensors
LIDAR Connectors
Logic Shifting
ARM Cortex M4
USB/Ethernet
Other Connectors



Board: 4 copper layers, 60.0 x 80.0 mm, 112 parts (40 on the bottom side), 117 nets.

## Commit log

2018-02-16 added mcad and ecad directories
    [Apple 2.0C Breakout Board.brd, Battery Button Board.brd, Battery Button Board.sch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]
2018-03-19 Started V3 Design
    [Apple 2.0C Breakout Board.brd, Battery Button Board.brd, Battery Button Board.sch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]
2018-03-22 Added Flight ESCs and power supply to PowerSwitchingBoard
    [PowerSwitchingBoard.brd, PowerSwitchingBoard.sch]
2018-03-23 Added connectors
    [GimbalIMUBoard.brd, GimbalIMUBoard.sch, PowerSwitchingBoard.brd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]
2018-03-23 Started routing programming traces
    [PowerSwitchingBoard.brd]
2018-03-23 Revert "Started routing programming traces"
    This reverts commit 430756d4e182701a37896144ea8eedb7b4574f9e.
    [PowerSwitchingBoard.brd]
2018-03-23 Revert "Revert "Started routing programming traces""
    This reverts commit ddc17bf72af711ebc9306e9f8ba822a91bb19f68.
    [PowerSwitchingBoard.brd]
2018-03-25 Fixed consistancy errors and finished routing
    [PowerSwitchingBoard.brd, PowerSwitchingBoard.sch]
2018-03-27 Started Flight Controller Board Design
    [FlightControllerBoard.brd, FlightControllerBoard.sch]
2018-03-28 Finished overall board zoning and component placement
    [FlightControllerBoard.brd, FlightControllerBoard.sch]
2018-03-28 Repositioned ethernet pullup resistors
    [FlightControllerBoard.brd, FlightControllerBoard.sch]
2018-03-30 Routed more traces, recognized that PowerSwitchingBoard connector needs to be reversed
    [FlightControllerBoard.brd, FlightControllerBoard.sch, PowerSwitchingBoard.brd]
2018-04-03 Finished Power Switching Board and Flight Controller Board v1
    [FlightControllerBoard.brd, FlightControllerBoard.sch, PowerSwitchingBoard.brd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]
2018-04-04 Added Halo drone assembly archive file
2018-04-30 Changed ethernet capacitor isolation to transformers
    [FlightControllerBoard.brd, FlightControllerBoard.sch, PowerSwitchingBoard.sch]
2018-06-02 Created TOF Altimeter Board v1, and made power board 4 layers
    [FlightControllerBoard.brd, FlightControllerBoard.sch, PowerSwitchingBoard.brd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]
2018-06-04 finished power board v1.2
    [PowerSwitchingBoard.brd, PowerSwitchingBoard.sch]
2018-07-10 About to remove touchscreen from controller board
    [BulkBoard1.brd, BulkBoard2.brd, BulkBoard3.brd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]
2018-07-12 Finished controller board v1.5
    [Controller Board.brd, Controller Board.sch]
2018-07-26 Added new battery and joystick modules
    [Battery Control.brd, Battery Control.sch, Controller Board.brd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]
2018-07-27 Changed folder name
    [Apple 2.0C Breakout Board.brd, Battery Button Board.brd, Battery Button Board.sch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]
2018-07-30 Fixed USB C connector sheild pin short problem
    [Controller Board.brd, Controller Board.sch]

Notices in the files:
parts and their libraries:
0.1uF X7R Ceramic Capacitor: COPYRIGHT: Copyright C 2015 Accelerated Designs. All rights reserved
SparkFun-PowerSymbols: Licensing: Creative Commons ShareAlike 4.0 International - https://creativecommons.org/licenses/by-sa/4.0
